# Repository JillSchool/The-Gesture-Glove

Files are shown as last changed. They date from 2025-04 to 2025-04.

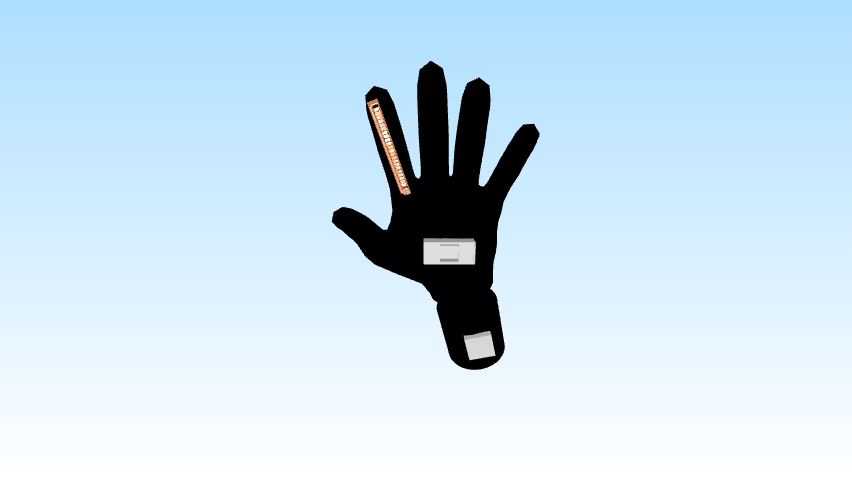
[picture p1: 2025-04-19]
Ontwerp/Gesture Glove/glove_design_v2.gif

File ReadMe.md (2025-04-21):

# The Gesture Glove – Tinlab1 Embedded Systems

In deze opleverset is het project *The Gesture Glove* van Tinlab1 Embedded Systems te vinden. De Demo videos en presentatie staan alleen in de opleverset.

## 📁 Onderdelen Opleverset

### 📂 Code

- **Auto**  
  Bevat de code voor de auto.

- **Gesture Glove**  
  Bevat de code voor de Gesture Glove.

- **Simulatie**  
  Bevat de simulatiewereld inclusief bijbehorende controllers.

- **TestCodes**  
  Bevat drie test codes gebruikt voor het project.

---

### 📂 Demo

- **Presentatie** 
  Bevat de eindpresentatie
  
- Bevat demo-video's:
  - Eén met de auto
  - Eén met de simulatie

---

### 📂 Documentatie

- **Handleiding**  
  Handleiding van de Gesture Glove.

- **Onderzoeken**  
  Sensoronderzoek.

- **Overig**  
  Informatie over de content van het displayscherm en de Gesture Glove.
  De projectdoelenchecklist.
  Een verslag met daarin alle belangrijke gegevens van het project.

- **Paper**  
  Engelstalige paper over het project.

- **Testen**  
  Testplan en testrapport.

- **Userstorys en requirements**  
  Bevat:
  - Moscow-document  
  - Requirements  
  - Userstory's met bijbehorende acceptance criteria

---

### 📂 Ontwerp

- **Elektrisch Schema**
  - **Auto**  
    Elektrisch schema van de auto.
  - **Gesture Glove**  
    Elektrisch schema van de Gesture Glove.

- **Gesture Glove**  
  Ontwerp van de Gesture Glove, het ontwerp voor het displayscherm en een architectuur diagram.

---

## Startpunt

Om de opleverset zo goed mogelijk te begrijpen is het van belang om te beginnen bij het document: Documentatie/Overig/The Gesture Glove. In dit document worden de context van het project, de hoofd- en deelvragen, de behaalde technische doelstellingen en een advies voor de verdere ontwikkeling van het project beschreven.

## Linkjes
- **Git:**
  https://github.com/JillSchool/The-Gesture-Glove.git
- **Trello:**
  https://trello.com/invite/b/67acb1cadb1ab3d7d48880f9/ATTIae5f5ea5cc120697c15d977ca467ee1fF77474C3/planning

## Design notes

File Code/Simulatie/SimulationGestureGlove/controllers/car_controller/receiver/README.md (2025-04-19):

# RX_BLE.py

## Overview

The `rx_ble.py` script facilitates communication between a BLE-enabled motion detection glove and a Webots simulation. It is designed to handle BLE device scanning, establish a TCP connection with Webots, and manage data transmission between the BLE device and the Webots simulation.

## Features

- Scans for available BLE devices.
- Connects to a Webots simulation via a TCP socket.
- Receives data from a BLE-enabled glove and forwards it to Webots.
- Sends test messages to Webots to verify the connection.
- Handles BLE disconnection events gracefully.

## Requirements

- Python 3 (tested with Python 3.12)
- Install the required Python packages listed in `requirements.txt`.

## Constants

- `GLOVE_ESP32_BLE_ADDRESS`: BLE address of the glove ESP32 device.
- `GLOVE_ESP32_BLE_CHARACTERISTIC_UUID`: UUID of the BLE characteristic to read data from.
- `WEBOTS_TCPIP_IP_ADDRESS`: IP address for the Webots TCP connection.
- `WEBOTS_TCPIP_PORT`: Port for the Webots TCP connection.

## Global Variables

- `webots_reader`: Reader object for Webots TCP connection.
- `tx_writer`: Writer object for Webots TCP connection.
- `cmd_prev`: Stores the previous command received from BLE.

## Functions

### `main()`

The main function manages BLE and Webots connections. It initializes BLE scanning, connects to Webots, and handles BLE data reception.

### `scan_ble_devices()`

Scans for available BLE devices and prints their details.

### `connect_to_webots()`

Establishes a TCP connection to the Webots simulation.

### `close_connection()`

Closes the TCP connection to Webots.

### `cleanup()`

Resets global variables and events for cleanup.

### `test_webots_connection(message="P")`

Sends a test message to Webots to verify the connection.

### `rx_from_ble()`

Receives data from the BLE device and forwards it to Webots.

### `tx_to_webots(message)`

Sends a message to Webots via the TCP connection.

### `loop_iteration(use_scan=False, use_connect=True, use_test=False, use_rx=True)`

Performs a single iteration of the main loop, handling BLE scanning, Webots connection, test message sending, and BLE data reception.

## Usage

1. Ensure Python 3.7 or higher is installed.
2. Install the required Python packages using `requirements.txt`:

   ```bash
   pip install -r requirements.txt
   ```

3. Run the script using Python:

   ```bash
   python rx_ble.py
   ```

4. The script will scan for BLE devices, connect to Webots, and handle data transmission.

## Notes

- Update the `GLOVE_ESP32_BLE_ADDRESS` constant with the correct BLE address of your glove device.
- Ensure Webots is running and accessible at the specified IP and port.

## License

This script is provided under the MIT License. See the LICENSE file for details.

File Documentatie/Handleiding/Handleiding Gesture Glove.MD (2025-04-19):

# Handleiding Gesture Glove

## Inhoudsopgave
- [Handleiding Gesture Glove](#handleiding-gesture-glove)
  - [Inhoudsopgave](#inhoudsopgave)
  - [1. Introductie](#1-introductie)
  - [2. Benodigdheden](#2-benodigdheden)
    - [2.1 Hardwarecomponenten van de Gesture Glove](#21-hardwarecomponenten-van-de-gesture-glove)
    - [2.2 Hardwarecomponenten van de auto](#22-hardwarecomponenten-van-de-auto)
    - [2.3 Software](#23-software)
  - [3. Werking van de Gesture Glove](#3-werking-van-de-gesture-glove)
    - [Bewegingen](#bewegingen)
    - [Extra functionaliteiten](#extra-functionaliteiten)
    - [OLED-scherm weergave](#oled-scherm-weergave)
      - [Linkerkant:](#linkerkant)
      - [Rechterkant:](#rechterkant)
    - [Verbinden met simulatie of fysieke auto](#verbinden-met-simulatie-of-fysieke-auto)
    - [ChangeLog](#changelog)

---

## 1. Introductie

De **Gesture Glove** is een project dat handbewegingen meet en doorstuurt naar een eindapparaat, zoals een RC-auto of een simulatieprogramma. Deze methode van data-overdracht biedt een alternatieve manier om apparaten aan te sturen en opent nieuwe toepassingen.

In dit project wordt de data gebruikt om een RC-auto te besturen in zowel de fysieke als de virtuele (simulatie) wereld. In deze handleiding wordt uitgelegd hoe het systeem werkt, welke onderdelen je nodig hebt en hoe je ermee aan de slag gaat.

---

## 2. Benodigdheden

Om dit project zelf op te bouwen, heb je de volgende hardware en software nodig:

### 2.1 Hardwarecomponenten van de Gesture Glove
- LilyGO TTGO T2 ESP32-WROOM (microcontroller met ingebouwd OLED-scherm)
- MPU6500 (versnellingsmeter en gyroscoopsensor)
- Flex sensor  
- Drukknop  
- Batterij

### 2.2 Hardwarecomponenten van de auto
- 4 DC-motoren  
- 4 wielen  
- ESP32S (microcontroller)  
- L293D motor driver  
- Batterij

### 2.3 Software
- Webots (simulatieomgeving)  
- Arduino IDE (voor het programmeren van de microcontrollers)

---

## 3. Werking van de Gesture Glove

De Gesture Glove maakt gebruik van verschillende sensoren om de beweging van je hand te registreren. Deze informatie wordt draadloos via **Bluetooth (BLE)** verzonden naar zowel de simulatie als de fysieke auto.

### Bewegingen
- **Voor- en achteruit:** De MPU6500 detecteert de kanteling van je hand. Kantel je hand naar voren, dan rijdt de auto vooruit. Kantel je hand naar achter, dan rijdt hij achteruit.
- **Links/rechts:** Bij kanteling naar links of rechts beweegt de auto in dezelfde richting.

### Extra functionaliteiten
- **Flex sensor:** Detecteert of je een vuist maakt. Als je een vuist maakt, remt de auto direct.
- **Drukknop:** Schakelt alle functies uit. Na 5 seconden gaat de glove in slaapmodus. Deze vertraging voorkomt dat een per ongeluk indrukken meteen tot slaapmodus leidt.

### OLED-scherm weergave
Op het scherm van de ESP32 worden realtime gegevens getoond:

#### Linkerkant:
- 🔋 **Batterij en hand:** Percentage van de batterij van de Gesture Glove  
- 📶 **Verbinding:** Signaalsterkte tussen de glove en de auto (fysiek of simulatie)  
- 🔋 **Batterij en stuur:** Batterijniveau van de fysieke auto  
- 🚗 **Snelheidsmeter:** Toont de snelheid van het voertuig  

#### Rechterkant:
- ❌ **'X'-icoon bovenaan:** Geeft aan of de werking is uitgeschakeld door de knop (hardware interrupt)  
- 🧭 **Richting onderaan:** Richting van de hand zoals gemeten door de IMU  
  - De gekleurde cirkel geeft de status van de rem aan:
    - **Groen & klein:** Geen vuist → geen rem  
    - **Rood & groter:** Vuist → rem actief  

---

### Verbinden met simulatie of fysieke auto

- **Simulatie:** Start de Webots-wereld en run het bijbehorende Python-script om verbinding te maken via BLE.
- **Fysieke auto:** Sluit de auto aan op stroom. De verbinding met de Gesture Glove wordt automatisch opgezet via BLE.

---

### ChangeLog

| Versie | Datum | Wijziging |
|---|---|---|
| 0.1 | 14-04-2025  | Document aangemaakt  |
| 1.0 | 15-04-2025  | Informatie toegevoegd |

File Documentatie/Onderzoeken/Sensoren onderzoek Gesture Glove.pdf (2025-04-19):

## Sensoren onderzoek Gesture Glove

## 1. Introductie

In dit onderzoek zijn de onderbouwde keuzes terug te vinden die gemaakt zijn om voor bepaalde hardware en software te kiezen.

## 2. Hardware

2.1 Microcontroller Gesture Glove
Om de data van de Gesture Glove te kunnen verwerken en sensorwaarden betrouwbaar te kunnen meter, is een geschikte microcontroller nodig. Deze moet krachtig genoeg zijn om meerdere sensoren tegelijkertijd aan te sturen, verbinding te maken met andere apparaten, en data in realtime te verwerken en eventueel weer te geven op een display. Ook is het van belang dat het een Low-power microcontroller is, zodat de batterij langer meegaat. Er is onderzoek gedaan naar een aantal microcontrollers.
- Arduino
De Arduino is een gebruikersvriendelijke en toegankelijke microcontroller. Deze is ideaal voor kleinschalige projecten, maar mist de ingebouwde communicatiemogelijkheid van Wifi of Bluetooth. Ook heeft de Arduino een gelimiteerde rekenkracht, wat voor dit project wel nodig is dankzij de meerdere sensoren en realtime dataverwerking. Ook moet je bij gebruik van de Arduino een extra OLED-display aansluiten.
- Raspberry Pi
De Raspberry Pi is een krachtige microcontroller. De Raspberry Pi bevat ingebouwde Wifi en Bluetooth. Het stroomverbruik is wel relatief hoog, en de Raspberry Pi zelf is te groot voor het project. De Raspberry Pi Pico is dan wel een stuk kleiner, maar bevat dan weer geen ingebouwde Wifi of Bluetooth. Ook zou je voor beide microcontrollers een extra OLED-display moeten aansluiten.
- ESP32s
De ESP32s, of de ESP Wroom 32, is een relatief kleine microcontroller met ingebouwde Wifi en Bluetooth. De microcontroller is geschikt voor het realtime verwerken van de data en het draadloos te communiceren met bijvoorbeeld een fysieke auto of simulatie wereld. Ook is de ESP32s energiezuinig. Alleen moet je voor deze ESP ook een externe OLED-Display hebben.
- ESP32 ESP-WROOM-32 met een 0.96" OLED-display
Deze versie van de ESP32 heeft alle voordelen van een ESP32 maar dan met een ingebouwde OLED-display scherm.
- LilyGO TTGO T2 ESP32-WROOM
De LiliGO is een variant van de ESP32 met een geïntegreerd OLED-Display scherm. Ook heeft deze ESP de mogelijkheid van Wifi en Bluetooth, is energiezuinig en is compact genoeg voor de Gesture Glove. Ook heeft deze microcontroller al een ingebouwde OLED-Display. De krachtige LiliGO TTGO T2 ESP32-WROOM is een ideale microcontroller.
Na een aantal Microcontrollers voor de Gesture Glove vergeleken te hebben, kunnen we concluderen dat de LiliGO TTGO T2 ESP32-WROOM de beste keuze is. Deze microcontroller voldoet aan alle eisen die nodig zijn binnen het project. Hij is energiezuinig, heeft de mogelijkheid om Wifi en Bluetooth te gebruiken en heeft een ingebouwde OLED-Display om de data realtime te kunnen laten zien.
2.2 Microcontroller Fysieke auto
Ook de fysieke auto heeft een microcontroller nodig. Deze microcontroller moet 4 wielen kunnen aansturen en via Wifi of Bluetooth data kunnen ontvangen van de Gesture Glove. Ook moet de microcontroller niet al te veel energie verbruiken.
- Arduino
De Arduino is een gebruikersvriendelijke en toegankelijke microcontroller. Deze is ideaal voor kleinschalige projecten, maar mist de ingebouwde communicatiemogelijkheid van Wifi of Bluetooth. Hierdoor is deze niet geschikt voor de auto.
- Raspberry Pi
De Raspberry Pi is een krachtige microcontroller. De Raspberry Pi bevat ingebouwde Wifi en Bluetooth. Het stroomverbruik is wel relatief hoog. De Raspberry Pi Pico verbruikt minder energie, maar bevat dan weer geen ingebouwde Wifi of Bluetooth. Deze zijn dus ook niet geschikt voor de auto.
- ESP32s

De ESP32s, of de ESP Wroom 32, is een relatief kleine microcontroller met ingebouwde Wifi en Bluetooth. De microcontroller is geschikt voor het realtime verwerken van de data en het draadloos te communiceren met de Gesture Glove. Hierdoor is deze ESP een goede keuze voor de auto.
Voor de auto is gekozen om gebruik te maken van de ESP32s. Deze microcontroller verbruikt minder energie en kan communiceren via Wifi en Bluetooth. Een prima microprocessor voor de auto.

2.3 Beweging detectie
Om de beweging van iemand hand te kunnen detecteren is er een sensor nodig. De sensor moet kunnen detecteren dat iemand zijn hand beweegt. De sensor moet dus een acceleratie meter en een gyroscoop bevatten. Een magnetometer is geen verijsde, maar we een voordeel als de sensor het bevat. Ook moet de sensor klein en licht zijn, zodat hij op de handschoen geplaatst kan worden.
- LSM6DS3
De LSM6DS3 sensor is een sensor die de gyroscoop van 3 assen kan meten en de acceleratie van 3 assen. De sensor is energiezuinig en werkt met I2C. De sensor bevat alleen geen magnetometer, dus er is geen absolute oriëntatie.
- LSM9DS1
De LSM9DS1 sensor meet de gyroscoop van 3 assen, de acceleratie van 3 assen en heeft de 3-assige magnetometer. Het is een krachtige sensor met veel opties. Helaas maakt dit de sensor moeilijk om mee te werken en duurder dan de andere alternatieven.
- BMI160
De BMI160 is een sensor met een zeer laag energiegebruik. De sensor heeft de gyroscoop en de acceleratie meter. Deze waardes worden gemeten met zeer hoge precisie. De sensor bevat geen magnetometer.
- BNO055
De BNO055 is een complexe sensor die een groot aantal data kan meten. Zo meet de sensor de acceleratie, gyroscoop, magnetometer en bevat hij een intern algoritme voor absolute oriëntatie. Het nadeel hiervan is dat de sensor een hoge energieconsumptie heeft en groter is dan de andere alternatieven. Ook is deze sensor een stuk duurder.
- MPU9250/6500
De MPU9250/6500 is een sensor met een 3-assige gyroscoop, 3-assige acceleratiemeter en een 3-assige magnetometer. De sensor is relatief klein en licht. De sensor is makkelijk om te gebruiken.
Voor het meten van de beweging van je hand is er gekozen voor de MPU9250/6500 sensor. De sensor kan alle assen meten en is makkelijk te gebruiken voor het project. Ook is hij licht en kosten efficiënt.

2.4 Buiging detectie
Een andere beweging van de hand die gedetecteerd moet kunnen worden is de buiging van je hand. De sensor moet dus kunnen meten of jij een vuist maak door de verbuiging van je vingers.
- Bend sensor
Deze sensor is dun en flexibel. Hij is relatief makkelijk te gebruiken, maar heeft een korte levensduur bij veel buigen.
- ToF (Time of Flight) sensor
Deze sensor meet de afstand tussen je vingertop en je handpalm. Het is een nauwkeurige sensor. Echter is deze sensor gevoelig voor licht en reflectie, en is hij moeilijk in de handschoen te verwerken.
- Flex sensor
Deze sensor is makkelijk te gebruiken, hij is licht en makkelijk te implementeren. De sensor is niet extreem nauwkeurig, maar het kan detecteren wanneer je een vuist maak.
Voor het project Gesture Glove is gekozen voor de Flex sensor. De sensor is makkelijk te gebruiken en kan de buiging van je vingers meten. De data is dan niet extreem nauwkeurig, maar dat maakt voor dit project niet heel veel uit.

## 3. Software

3.1 Simulatie wereld
Om de sensor waardes te kunnen visualiseren in een online omgeving, is er een simulatie wereld nodig. Om deze wereld te maken moet er eerst gekeken worden naar de mogelijke simulatieprogramma’s. Het simulatieprogramma moet makkelijk te gebruiken zijn, realtime data kunnen ontvangen en verwerken en moet verbinding kunnen maken via bluetooth of Wifi.
- Gazebo
Gazebo is een populaire roboticasimulator die goed integreert met ROS en meerdere sensoren en hardware kan aansturen. Hoewel het zeer nauwkeurig is voor het simuleren van fysica en robotbesturing, bleken de mogelijkheden te geavanceerd voor dit project, waarin eenvoudige visualisatie van beweging voldoende is.
- Webots
Webots is een andere simulatieomgeving voor robotica met een gebruiksvriendelijke interface, wat het eenvoudig maakt om realtime sensordata te simuleren en te visualiseren. Hoewel het niet dezelfde diepe integratie met ROS biedt als Gazebo, is de eenvoud en efficiëntie van Webots ideaal voor het visualiseren van basis-handbewegingen op basis van sensorgegevens.
- Unity
Unity, dat vooral bekend staat als game engine, biedt hoge grafische kwaliteit en flexibiliteit voor het creëren van aangepaste visualisaties. De geavanceerde functies zijn echter vooral nuttig bij complexe simulaties, waardoor Unity minder efficiënt is voor onze behoeften, die zich richten op eenvoudige visualisatie van handbewegingen.

Na een aantal simulatieprogramma’s vergeleken te hebben, kan geconcludeerd worden dat Webots een goed simulatieprogramma is voor dit project. Het is makkelijk te gebruiken, maar bied genoeg functionaliteiten om voor het project ingezet te kunnen worden.
3.2 Programmeertalen
Nadat er gekozen is voor de ESP microcontrollers is er gekozen om deze te programmeren in de Arduino IDE. Hierom is de programmeertaal C/C++ gekozen.
De controller van de simulatie is geschreven in C.
De Bluetooth communicatie is geschreven in python.
Voor extra test bestanden is gekozen voor python.

## 4. Conclusie

Nu we voor alle componenten verschillende alternatieven onderzocht hebben, kunnen we nu een conclusie trekken per onderdeel.

De microcontroller voor de Gesture Glove is de LiliGO TTGO T2 ESP32-WROOM geworden. Het is een krachtige ESP met de mogelijkheid voor Wifi en Bluetooth. Ook heeft deze ESP een ingebouwde OLED-Display scherm waarop data geprint kan worden.
De microcontroller voor de Fysieke auto is de ESP32S. Deze ESP heeft de mogelijkheid om te verbinden via Wifi en Bluetooth.
Om Beweging te kunnen detecteren is gekozen voor de MPU9250/6500. De sensor kan alle assen meten en relevante data teruggeven.
Voor de buiging detectie is gekozen voor de Flex sensor. Deze sensor kan duidelijk weergeven of je een vuist van je hand gemaakt hebt of niet.
Voor de Simulatiewereld is gekozen voor Webots. Het simulatieprogramma biedt genoeg mogelijkheden binnen dit project en is relatief makkelijk te gebruiken.
De programmeertalen die gebruikt gaan worden binnen het project zijn C, C++ en Python.

## 5. ChangeLog

ChangeLog
Versie | Datum | Wijziging
0.1 | 14-02-2025 | Document aangemaakt
0.2 | 09-03-2025 | Sensoren toegevoegd
1.0 | 14-04-2025 | Definitieve versie

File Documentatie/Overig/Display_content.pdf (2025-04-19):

# Display content

## All possible data:

- Battery life
- Orientation of IMU(as arrows)
- Status of flex sensor(together with arrows)
- Status of emergency button
- Current gesture
- Connectivity status
- Info on the car(speed, direction, battery life)

## Multiple screens

### A main screen:

Appears when all is ready to go. Will show useful information:

- Battery percentage of the glove ; percentage
- Signal strength between glove and end device ; great/good/bad/NC(not connected)
- Battery of the end device ; percentage
- Feedback from the end device like speed if possible ; km/h
- Status of the hardware/ emergency interrupt ; no/ yes?
- Orientation of the glove ; a moving circle in another bigger circle
- Resistance from the flex sensor ; a circle that gets bigger the more resistance

### An all black screen:

Appears while the device is in sleep mode.

## When will what action take place?

### Sleep mode:

When the hardware interrupt is used once and not disabled within 5 seconds.

### Watchdog timer:

Will make sure that the sensors are measuring, the data is being displayed and send within defined time frame.

### Hardware interrupts:

When a button is pushed, all data transfer will be stopped and the device will be put into sleep mode if not pressed again. When in sleep mode press the button to start the device.

### Software interrupts:

When the connection is lost send an interrupt to connect again before further action is taken.

### Using RTOS / embedded Linux:

The esp32 will use its multiple cores and RTOS task creations to execute functions.

### Reading a sensor:

The chosen sensors(IMU and flex) will be constantly read, displayed on the glove display and send to the end device.

### Control an actuator:

The send data from the sensors over Bluetooth or WIFI will be used to control step or other motors on the end device.

## ChangeLog

ChangeLog
Versie | Datum | Wijziging
0.1 | 09-04-2025 | Document aangemaakt
1.0 | 14-04-2025 | Definitieve versie

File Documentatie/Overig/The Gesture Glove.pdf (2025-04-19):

# The Gesture Glove

## Literatuuronderzoek en technische verantwoording

## 1. Context

The Gesture Glove is een innovatieve oplossing voor datavisualisatie en apparaat besturing. Met behulp van een slimme handschoen die handbewegingen meet, kunnen uiteenlopende eindapparaten, zoals RC-auto’s, drones of andere voertuigen, eenvoudig aangestuurd worden.
Deze technologie biedt waardevolle toepassingen in zowel de medische als de industriële sector. Denk hierbij aan ondersteuning bij revalidatierobot of het uitvoeren van precisiewerk in risicovolle of slecht bereikbare omgevingen.
The Gesture Glove verkent een nieuwe manier van menselijke interactie met technologie, door realtime handbewegingen niet alleen te detecteren, maar ook weer te geven in een simulatie en te gebruiken om een auto aan te sturen.
Voor de realisatie van dit project is uitgebreid onderzoek gedaan naar verschillende aspecten van de technologie. Hierbij is onder andere gekeken naar geschikte sensoren voor het meten van bewegingen, methodes voor het verwerken van de data, geschikte communicatieprotocollen zoals BLE, energiebeheer voor draagbare toepassingen en de aansturing van het systeem zelf.
Om het project doelgericht en gestructureerd uit te voeren, is een hoofdvraag opgesteld. Deze hoofdvraag wordt beantwoord aan de hand van meerdere deelvragen.

## 2. Hoofdvraag

Om goed van start te gaan met het project, is er eerst overlegd met de projectdocent om de haalbaarheid te bespreken. Hieruit zijn een aantal Userstory’s en Requirements opgesteld. Hieruit is er een Hoofdvraag geformuleerd: “Hoe kun je met behulp van een slimme handschoen handbewegingen detecteren en visualiseren?”

## 3. Deelvragen

Om de hoofdvraag te kunnen beantwoorden zijn er een aantal deelvragen geformuleerd.

### 1. Welke bewegingen moeten gemeten kunnen worden?

Voor de besturing van een voertuig is het essentieel om de kanteling van de hand op de X en Y as accuraat te kunnen meten. Op basis van de richting en snelheid van deze kanteling kan het voertuig worden aangestuurd qua richting én snelheid. Daarnaast is het herkennen van het maken van een vuist een belangrijke actie, bijvoorbeeld als signaal om te remmen of een systeem te pauzeren. Dit zijn de twee primaire bewegingen die binnen het project zijn geïdentificeerd.

### 2. Hoe kunnen deze specifieke bewegingen gemeten worden?

Deze bewegingen worden gemeten met behulp van een IMU-sensor (MPU6500) die rotatie-en versnellingsgegevens levert, en met Flex sensor die buiging van de vingers detecteren, zoals bij het maken van een vuist. De plaatsing van de sensoren is belangrijk om de precies de juiste metingen te kunnen verrichten.
Voor het kiezen van de sensoren is een apart sensoren onderzoek uitgevoerd. Dit onderzoek is terug te vinden in de opleverset. Uit het sensorenonderzoek blijkt dat de MPU9520/6500 vanwege zijn stabiliteit, I2C-compatibiliteit en nauwkeurige gyroscoop- en versnellingsdata de beste keuze was. Voor de Flex sensor is gekozen vanwege de eenvoud en effectiviteit bij het meten van vingerbewegingen.

### 3. Hoe kunnen de gemeten waarden gevisualiseerd worden?

De visualisatie gebeurt op twee manieren:
- Softwarematig: Via een simulatieomgeving Webots, waarin een racebaan of virtuele omgeving is gesimuleerd. De handschoen bestuurt daarin een virtueel voertuig. Uit het sensorenonderzoek kwam naar voren dat Webots de beste mogelijkheid biedt tussen compatibiliteit en eenvoudige integratie.
- Hardware matig: De ESP LilyGO TTGO T2 is verbonden met een OLED-display waarop realtime informatie wordt weergegeven, zoals handoriëntatie, verbindingssnelheid en batterijstatus. Daarnaast wordt een fysieke auto bestuurd met de data van de handschoen.

### 4. Hoe kan data het meest effectief worden verzonden van de ESP naar een laptop?

Voor een snelle en energiezuinige communicatie is gekozen voor Bluetooth Low Energy (BLE). Deze technologie maakt het mogelijk om continu data te verzenden zonder grote batterijbelasting. In de Engelse Paper is meer informatie te vinden over waarom deze keus gemaakt is.

## 4. Technische verantwoording

Binnen het TinLab Embedded Systems zijn er een aantal verijsde technische doelen. Hieronder een overzicht van deze technieken en hoe ze toegepast zijn binnen het project. Watchdog timer
- Voorkomt dat het system vastloopt. Als de sensor input niet op tijd ontvangen wordt, wordt het systeem automatisch gereset.

Sleep modus
- Wanneer de hardware interrupt gebruikt wordt en niet binnen 5 seconde nog een keer ingedrukt wordt, gaat de Gesture Glove in de Sleep modus.

Hardware interrupt
- Wanneer de knop van de hardware interrupt ingedrukt wordt, wordt er geen data meer verzonden. Hierdoor kan je je hand vrij bewegen zonder data te verzenden. Wanneer de hardware interrupt knop niet nog een keer ingedrukt wordt binnen 5 seconde, gaat de Gesture Glove in sleep modus. Wanneer de hardware interrupt nog een keer ingedrukt wordt, start de Gesture Glove weer opnieuw op.

Software interrupt
- Herlaad de icoontjes op het display om de actuele data te tonen door een software interrupt die elke 2 seconden afgaat.

Gebruik van RTOS/ Embedded Linux
- Dankzij het gebruik van RTOS op de ESP32 kunnen meerdere processen tegelijk draaien, zoals sensoruitlezing en communicatie.

Communicatie via I2C en/of SPI
- De IMU-sensor communiceert via het I2C-protocol.

Uitlezen van een sensor
- Zowel de IMU als Flex sensor worden continu uitgelezen.

Regelen van een systeem (bij voorkeur met PID-controller)
- De MPU-sensor verwerkt de rauwe gyroscoop data van de sensor doormiddel van een PID-regelaar. Hierdoor neemt de snelheid van het eindapparaat geleidelijk toe.

Aansturen van een actuator
- De motor van de fysieke auto wordt aangestuurd via een L293D-motor driver. Hiermee wordt de auto aangestuurd.

Interfacing met een display

- De ESP LilyGO TTGO T2 ESP32-WROOM heeft een ingebouwde OLED-display. Hierop is de richting te zien waarop de Gesture Glove beweegt. Ook is hier de batterij waarde te zien, de verbinding snelheid en of de hardware interrupt actief is.

## 5. Advies

Wanneer er gekozen wordt om verder te bouwen op het project van de Gesture Glove is er een aantal adviezen om naar te kijken. Ten eerste wordt er geadviseerd om meer onderzoek te doen naar de plaatsing van de hardwarecomponenten op de Gesture Glove zelf. Dit kan lijden tot snellere en nauwkeurigere metingen van de bewegingen. Hierbij kan ook gekeken worden wat de mogelijkheden zijn van het meer implementeren van de sensoren, bijvoorbeeld door de Flex sensor in de handschoen te plaatsen.
Als tweede advies wordt meegegeven om krachtigere motoren te plaatsen onder de fysieke auto. Dit zorgt ervoor dat de auto sneller kan rijden en er een duidelijk verschil in snelheid van de auto gezien kan worden.
Als derde wordt geadviseerd om onderzoek te doen naar nieuwe sensoren die gebruikt kunnen worden voor nog meer bewegingen te kunnen detecteren. Dit bied nog meer mogelijkheden voor het aansturen van fysieke objecten.

## 6. Conclusie

De hoofdvraag " Hoe kun je met behulp van een slimme handschoen handbewegingen detecteren en visualiseren?" is beantwoord door het combineren van verschillende sensoren en het draadloze communiceren tussen de Gesture Glove, simulatie en fysieke auto.
Uit de deelvragen blijkt dat de twee belangrijkste bewegingen die gemeten moeten worden, het kantelen van de hand en het maken van een vuist zijn.
Deze bewegingen zijn betrouwbaar meetbaar dankzij de MPU9520/6500-IMU en Flex sensor, gekozen op basis van het sensorenonderzoek.
De metingen worden gevisualiseerd in een simulatieomgeving (Webots) en via een OLED-display op de ESP32, en worden vertaald naar actie in een fysiek voertuig.
De dataverzending vindt plaats via BLE, wat op basis van de vergeleken opties in de paper de meest effectieve methode bleek.
Het project bevat alle elementen van een compleet Embedded systeem: van realtime dataverwerking en sensoraansturing tot motorsturing en draadloze communicatie. Het project toont de potentie van draagbare besturingstoepassingen in verschillende omgevingen. Wel wordt geadviseerd om te kijken naar een robuustere versie van de handschoen voor langdurig gebruik in realistische omgevingen

## 7. ChangeLog

ChangeLog
Versie | Datum | Wijziging
0.1 | 07-04-2025 | Document aangemaakt
0.2 | 17-04-2025 | Hoofd + deelvragen
1.0 | 19-04-2025 | Advies + conclusie

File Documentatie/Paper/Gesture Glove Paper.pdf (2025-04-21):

# Gesture Glove System: Sensor Accuracy, Display Efficiency, and Visualization

Prashant Chotkan, Jamai Esseboom, Jill den Ouden

Abstract—This research explores the optimization of gesture-based interfaces by evaluating the performance of key components in a gesture glove system, including the MPU6500 motion sensor, flex sensors, and the SSD1331 OLED display. The study focuses on improving gesture recognition accuracy and real-time visualization, addressing common challenges such as sensor inaccuracies and display latency. Experimental tests reveal that partial updates on the SSD1331 OLED display enhance refresh rates, while the MPU6500 sensor provides precise tracking of hand movements. Flex sensors positioned on the back of the finger demonstrate superior accuracy in detecting finger curvature. These findings offer valuable insights for the development of more responsive and accurate gesture-based control systems. Index Terms—gesture recognition, MPU6500, flex sensors, SSD1331 OLED, real-time visualization, gesture glove, human-computer interaction

I. INTRODUCTION

Gesture-based interfaces are increasingly used in various applications, from assistive technologies to virtual reality, yet optimizing their performance remains a challenge. Existing gesture recognition systems often suffer from limitations such as inaccurate sensor data, slow response times, and poor visualization of gestures, which hinder usability and effectiveness. This research aims to evaluate the key components of a gesture glove system, specifically motion sensors (MPU6500), flex sensors, and the SSD1331 OLED display, to determine their impact on gesture recognition accuracy and real-time visualization. Understanding the limitations and capabilities of these components will help improve gesture-based control systems, making them more reliable and responsive.
This research is valuable to engineers, developers, and researchers working in human-computer interaction, wearable technology, and assistive devices. By providing data-driven insights into component performance, this study contributes to the design of more efficient and accurate gesture-based interfaces, which can benefit applications in healthcare, gaming, robotics, and augmented reality.

II. ASSIGNMENT DESCRIPTION

A. Problem Definition

Gesture-based interfaces are widely used in applications such as assistive technology, virtual reality, and human-computer interaction. However, existing gesture recognition systems face several challenges that hinder their usability and effectiveness. These challenges include inaccurate sensor data, slow response times, and poor real-time visualization of gestures, all of which reduce the reliability of such systems.

One of the main limitations is the accuracy of motion tracking and finger curvature detection. Many systems rely on inertial measurement units (IMUs) and flex sensors, but their placement, calibration, and data processing methods significantly impact recognition accuracy. Some systems rely on a camera and ai technology to detect gestures and hand movements which are very prone to instability issues. Additionally, real-time visualization of gestures remains inefficient, as current display technologies may introduce latency or fail to represent movements smoothly.
This research addresses these challenges by evaluating the MPU6500 motion sensor, flex sensors, and the SSD1331 OLED display in a gesture glove system. The study investigates how sensor placement, data processing strategies, and display update techniques influence gesture recognition accuracy and real-time visualization performance. By identifying the limitations of these components, this research aims to improve gesture-based control systems, making them more responsive, precise, and suitable for applications in healthcare, gaming, robotics, and augmented reality.
B. Requirements
- Finger Curvature Detection – The system must accurately detect and measure the bending of the fingers.
- Glove Position and Direction Tracking – The system must determine the orientation and movement of the glove.
- Real-Time Data Processing – The system must process and interpret sensor data with minimal latency for immediate feedback.
- Wireless Data Transmission over Wi-Fi – The system must transmit gesture data wirelessly to an external device for further processing or visualization.
- Simulated Hand Representation – The system must include a virtual hand model that visually replicates the detected gestures in real time for verification and analysis.

III. RESEARCH QUESTIONS

This research focuses on the question: How can a gesture glove system effectively detect finger curvature, track hand position, and provide real-time visualization? To break this down further, the following subquestions are explored.
1) How do different update strategies and timing intervals affect the responsiveness of the SSD1331 display?
2) How effectively does an MPU6500 track the position and movement of the glove?

3) How does flex sensor placement influence accuracy in measuring finger curvature?
4) How to digitally simulate a hand using real-time collected sensor data?

IV. METHODS

A. SSD1331 Display

The SSD1331 is a 96×64 pixel OLED display commonly used in embedded systems. Its refresh rate directly impacts smoothness and responsiveness, making it crucial for real-time applications. This study examines how update strategies (full-screen vs. partial updates) and refresh timing intervals affect display performance.
1) Research Question: How does the refresh rate of the SSD1331 display respond to different update strategies and timing intervals?
We hypothesize that
- Updating fewer pixels results in a faster refresh rate.
- A minimum processing time is required per refresh cycle.
- Excessively frequent refreshes may cause rendering artifacts or frame skipping.
The study is conducted using a TTGO T2 ESP32 board with an SSD1331 OLED display, programmed in C with the Arduino framework. The evaluation consists of two test cases:
- Full-Screen vs. Partial Updates: Measuring refresh time for a full-screen update compared to a smaller region (e.g., 10×10 pixels).
- Effect of Refresh Interval: Varying update intervals from a few milliseconds to hundreds of milliseconds to assess performance, potential artifacts, and frame skipping.
Results will determine optimal update strategies for improving display performance in real-time applications.
B. MPU6500
1) Relevance of the MPU Sensor: The MPU6500 is essential for tracking hand movement and orientation. It detects shifts along the X, Y, and Z axes (acceleration) and tilting (gyroscope), ensuring reliable hand gesture recognition.
2) Choosing the Right MPU: The MPU9250 was initially selected for its 9 degrees of freedom (gyro, accelerometer, and magnetometer) [2], allowing precise movement and absolute orientation tracking. Its compact size, strong documentation, and wide library support make it ideal. While alternatives like the ICM-20948 exist, the MPU9250 balances performance and availability. For applications not requiring absolute orientation, the MPU6050 is a simpler alternative. However, for stable tracking with minimal drift, a magnetometer-equipped sensor is preferred.
3) MPU Sensor Testing: Testing revealed that the provided sensor was the MPU6500 instead of the expected MPU9250. Despite this, efforts focus on successfully integrating the MPU6500 into the system.
a) Including the Libraries: To interface with the MPU6500 sensor, it is advisable to use a library that facilitates communication over I²C or SPI, as outlined in the sensor’s specifications [1]. Several open-source libraries are available that support the MPU6500, simplifying data retrieval from the sensor. The test setup will require the MPU6500 sensor and a compatible micro controller for proper integration.
b) Test Cases: For the test cases you will need a MPU6500 sensor, a ESP32 and a pc/laptop running arduino.ide and python. To run the code for MPU6500 you first need to connect the sensor to the ESP32.
- GND – Connect to GND
- VCC – Connect to 3.3V
- SCL – Connect to GPIO 22
- SDA – Connect to GPIO 21
4) IMU Acceleration: This test ensures that the Acceleration meter within the MPU6500 works as expected. Requirement: The system must detect various movements along the X, Y, and Z axes. These movements correspond to shifts in hand position.
- Description: When the hand is moved, the sensor transmits data to the serial monitor, displaying the X, Y, and Z values.
- Steps:
1) Connect the sensor.
2) Move the hand.
3) Verify whether the movements are detected.
- Acceptance Criteria: The movements must be correctly detected and printed in the serial monitor.
5) IMU Gyroscope: This test ensures that the Gyroscope meter within the MPU6500 works as expected. Requirement: The system must detect various hand movements, specifically tilting.
- Description: When the hand is moved, data is transmitted to the serial monitor. The data can be checked by rotating the sensor and hold it to a 90 degrees angle.
- Steps:
1) Connect the sensor.
2) Move the hand.
3) Verify whether the movements are detected.
- Acceptance Criteria: The movements must be correctly detected and printed in the serial monitor.
6) IMU Gyroscope Accuracy: This test ensures that the gyroscope within the MPU6500 provides reliable readings. Requirement: When the sensor is held at different angles, it should return accurate values.
- Description: The sensor’s output is tested at various angles to verify accuracy.
- Steps:
1) Connect the sensor.
2) Hold the sensor at a 90-degree angle.
3) Verify whether the measured angle matches the actual orientation.
- Acceptance Criteria: The measured value must not deviate by more than 5 degrees from the actual angle.

7) IMU Acceleration Accuracy: This test ensures that the accelerometer within the MPU6500 provides reliable readings. A Python program is used to visualize sensor data by displaying a moving cube that mimics the sensor’s motion. Requirement: When moving the sensor, it should return accurate acceleration values corresponding to the movement.
- Description: The sensor’s accuracy is tested by comparing its output to the motion of a virtual cube on a screen.
- Steps:
1) Connect the sensor.
2) Close the serial monitor, then start the Python program.
3) Move the sensor at different speeds and directions.
4) Verify whether the cube’s movement matches the sensor’s motion.
- Acceptance Criteria: The cube on screen must move in the same direction as the sensor and stop when the sensor stops moving.
C. Flex Sensor

A flex sensor was chosen to measure the bending angle or curvature of the fingers due to its simplicity and effectiveness in detecting finger movements. Compared to other alternatives such as inertial measurement units (IMUs) or strain gauges, flex sensors offer a straightforward integration process, consume low power, and provide analog output that can be easily processed by a microcontroller. While IMUs are not suitable for measuring the curvature of the fingers specifically, they can be used for detecting other movements. Strain gauges can be used to measure finger curvature, but they require precise placement on the glove and are less accurate than a flex sensor while also being relatively more expensive.
To evaluate the performance of the flex sensor in detecting hand gestures, a controlled test setup was designed. The sensor was attached to the index finger at two different locations, as shown in Fig. 1:
1) Inside the finger (palm-side placement) – to measure curvature directly as the finger bends inward.
2) Outside the finger (backhand placement) – to analyze if it provides a more stable or accurate reading.
The sensor was connected to an ESP32 microcontroller’s Analog-to-Digital Converter (ADC) pin to continuously measure the resistance change as the finger moves. A custom testing procedure was followed:
- The hand started in a fully open and straight position.
- The subject gradually curled their fingers into a tight fist over a period of 5 seconds.
- ADC values were recorded in real-time and logged for analysis.
- The test was repeated multiple times to ensure consistency and identify the optimal placement of the sensor.

Fig. 1. Flex Sensor Placement

This experiment aimed to determine the most effective sensor placement by analyzing the signal consistency. By systematically comparing the ADC readings, the goal was to identify the placement that provides the clearest and most reliable data for detecting hand gestures accurately.

D. Simulation

To visualize the sensor data in real-time, we evaluated three simulation programs: Gazebo, Webots, and Unity. The primary goal was to simulate hand movements based on real-time sensor input without requiring complex features such as collision detection. The simulation program simply needed to receive and visualize the sensor data, translating it into hand movements.
1) Simulation Program Evaluation: The programs will each be tested separately by setting them up and trying a simple simulation. We compared the three simulation tools based on their ease of use and ability to visualize hand movements effectively.
- Gazebo: Gazebo is a popular robotics simulator that integrates well with ROS and can handle multiple sensors and hardware. While it is highly accurate for simulating physics and controlling robots, its capabilities were found to be more advanced than necessary for this project, where simple movement visualization suffices.
- Webots: Webots is another robotics simulation tool with a user-friendly interface, making it easy to simulate and visualize real-time sensor data. While it lacks the deep integration with ROS found in Gazebo, its simplicity and efficiency make it ideal for visualizing basic hand movements based on sensor inputs.
- Unity: Unity, typically used for game development, offers high-quality graphics and flexibility for creating custom visualizations. However, its advanced features are better suited for complex simulations, making it less efficient for our needs, which focused on straightforward hand movement visualization.
V. RESULTS
A. SSD1331 Display

The collected data shows the following trends:

- Full-screen updates take significantly longer than partial updates. The function fillScreen() required approximately 172 ms to complete, whereas updating a small 10x10 pixel region only took around 3 ms.
- Partial updates are significantly more efficient than full-screen redraws. This suggests that applications should avoid unnecessary full refreshes and instead update only necessary regions to optimize performance.
- No missing frames were observed even at high refresh rates. To verify this, slow-motion recording was used, which confirmed that frames were rendered sequentially without drops or skips.

B. MPU6500
All tests for the MPU6500 sensor were successfully executed, verifying its expected functionality. The results for each test are summarized below:
1) IMU Acceleration Test: The sensor correctly detected motion along the X, Y, and Z axes. Data was displayed in the serial monitor, confirming expected functionality.
2) IMU Gyroscope Test: The gyroscope accurately detected tilting movements. At a 90-degree angle, the measured values corresponded to the expected rotation, meeting the acceptance criteria.
3) IMU Gyroscope Accuracy Test: Measured values deviated by no more than 3 degrees from expected orientations, within the ±5-degree tolerance, confirming accuracy.
4) IMU Acceleration Accuracy Test: A Python program displayed a virtual cube mimicking sensor movement. The cube moved accurately in sync with the sensor, verifying data reliability.
All acceptance criteria were met, demonstrating the MPU6500’s capability to measure acceleration and angular velocity reliably in motion detection applications.
C. Flex Sensor
The results of the flex sensor tests demonstrated that both placements provided similar trends in ADC readings, ranging from 0 (completely unbent) to a maximum of 3038 (tight fist). However, the backhand placement showed slightly lower maximum adc value indicating a lower measuring range.
Time (s) | 0 | 1 | 2 | 3 | 4 | 5
Palm-Side Placement | 0 | 751 | 1507 | 2251 | 2898 | 3038
Backhand Placement | 0 | 724 | 1478 | 2207 | 2854 | 3030
TABLE I
ADC READINGS OVER TIME FOR FLEX SENSOR AT DIFFERENT PLACEMENTS.

As seen in Table I, the palm-side placement provided slightly more curvature compared to the backhand placement, which showed minor variations in maximum ADC values. Furthermore bending of the flex sensor when placed palm-side appeared more difficult as bending the fingers decreases the surface on which the flex sensor is mounted. This leads to the flex sensor getting loose from the finger. On the backhand placement the flex sensor is more stable as the contact surface increases a little when bending the fingers. This indicates that the sensor is more stable when positioned on the backhand.

D. Simulation
After comparing and testing the three options, Webots was selected as the most suitable tool for this project due to its balance of simplicity, and ease of use in real-time data visualization. Furthermore this program was easiest to setup overall, making it more accessible for rapid prototyping and iteration. Its user-friendly interface, combined with robust documentation and community support, facilitated quick development cycles, which were crucial for meeting project deadlines

VI. CONCLUSION
This study successfully integrated key components for a gesture-controlled embedded system, with a focus on performance optimization and accurate hand gesture recognition. The MPU6500 sensor proved reliable for motion and orientation tracking, ensuring precise hand movement detection through both accelerometer and gyroscope data. The flex sensor, placed on the backhand, provided consistent and accurate curvature detection, essential for recognizing gestures like bending. The SSD1331 display showed improved performance when using partial updates, avoiding frame loss and ensuring smoother real-time interactions. Webots was chosen as the simulation tool for its ease of use and effective visualization of real-time sensor data. This work demonstrates the importance of sensor placement and optimization in achieving reliable gesture recognition and provides a foundation for enhancing real-time embedded applications. Further testing could explore the impact of different display controllers, SPI clock speeds, and alternative sensor placements to further improve system performance.

VII. REFERENCES

1) TDK InvenSense, MPU-6500 Product Specification,
Revision | 1.3, | Document | Number: | PS-MPU-
6500A-01, | June | 2020. | [Online]. | Available:
https://invensense.tdk.com/wp-content/uploads/2020/06/PS-MPU-6500A-01-v1.3.pdf
2) InvenSense Inc., “MPU-9250 Product Specification,” PS-MPU-9250A-01, Jun. 2016. [Online]. Available: https://invensense.tdk.com/wp-content/uploads/2015/02/PS-MPU-9250A-01-v1.1.pdf
3) LilyGO, “GitHub - LilyGO/TTGO-T2-SSD1331-SD: TTGO-T2 V1.6,” GitHub. Available: https://github.com/LilyGO/TTGO-T2-SSD1331-SD

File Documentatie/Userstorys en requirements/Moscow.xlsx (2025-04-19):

Moscow
Must
1 | De handschoen bevat een sensor die het bewegen van je hand kan meten. Deze waardes worden doorgestuurd naar een simulatie programma.
2 | De handschoen bevat een sensor die de rotatie van je hand kan meten. Deze waardes worden doorgestuurd naar een simulatie programma.
3 | De handschoen bevat een sensor die het maken van een vuist kan meten. Deze waardes worden doorgstuurd naar een simulatie programma.
4 | Belangrijke waardes van de handschoen worden geviaualiseerd op de display van de ESP.
5 | Een simulatie programma kan alle gemete waardes weergeven.
6 | Het project moet gebruik maken van een watchdog timer
7 | Het project moet gebruik maken van een sleep modus
8 | Het project moet gebruik maken van een hardware interrupt (button) | Het indrukken van de knop zorgt ervoor dat de sensor waardes niet langer doorgestuurd worden, waardoor je je hand vrij kan bewegen. De display gaat in sleep modus.
9 | Het project moet gebruik maken van een software interrupt (Flex sensor)
10 | Het project moet gebruik maken van RTOS
11 | Het project moet gebruik maken van SPI en I2C (ESP en IMU)
12 | Het project moet gebruik maken van een PID (IMU)
13 | Het project moet een actuator aansturen
14 | Het project is verbonden door middel van WiFi/bluetooth
Should
15 | De sensor waardes stuurt een motor aan. Nog geen complete auto.
Could
16 | De sensor waardes sturen een autotje aan.
17 | De handschoen trilt als feedback.
18 | Een button zet de glove compleet uit.
Won't

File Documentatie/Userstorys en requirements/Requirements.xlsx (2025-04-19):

Requirement ID | Requirement | Task
1 | Er moet onderzoek gedaan worden naar welke sensoren het beste gebruikt kunnen worden. | Onderzoek naar de mogelijkheden van sensoren
2 | De IMU sensor moet beweging meten op de X, Y en Z as | Het systeem moet in staat zijn om de positie van de hand in de X, Y en Z dimensies te meten door middel van de IMU sensor. De X, Y en Z waardes moeten real-time gemeten worden en weergegeven in de Terminal of Serial monitor.
3 | De IMU sensor moet rotatie meten | Het systeem moet in staat zijn om de rotatie van de hand te meten door middel van de IMU sensor. De rotatie waardes moeten real-time gemeten worden en weergegeven in de Terminal of Serial monitor.
4 | De Flexsensor moet de buiging van de vinger meten/ het maken van een vuist | Het systeem moet in staat zijn om de buiging van de hand te meten door middel van de Flex sensor. De buiging waardes moeten real-time gemeten worden en weergegeven in de Terminal of Serial monitor.
5 | De ESP Display moet de batterijstatus weergeven | Het systeem moet de batterijstatus van de Gesture-Control Glove meten en bijhouden. De batterij status moet worden weergegeven op de ESP Display.
6 | De IMU waardes van de X, Y en Z as moeten op de ESP Display weergeven worden | De ESP Display moet real-time de waardes van de bewegingsrichting tonen
7 | De IMU waareds van de rotatiemoet op de ESP Display weergeven worden | De ESP Display moet real-time de waardes van de rotatie tonen
8 | De Flexsensor waarde moet op de ESP Display weergeven worden | De ESP Display moet real-time de waardes van de Flexsensor tonen
9 | Er moet een knop zijn die de sensor input stopt | Het systeem moet een fysieke knop bevatten waarmee de gebruiker de sensorinput tijdelijk kan uitschakelen. Wanneer de knop ingedrukt wordt, moet het systeem direct stoppen met het versturen van de sensor waardes
10 | Alle gemete sensor waardes moeten gestuurd worden naar een simulatie programma | Er moet onderzocht worden welk simulatie programma het meest geschikt is voor het project. Het programma moet alle sensor waardes ontvangen en netjes visualiseren.
11 | Er moet onderzoek gedaan worden naar of Wifi of Bluetooth een betere oplossing is voor het versturen van data. | Onderzoek naar de mogelijkheden van wifi en bluetooth voor dit project.

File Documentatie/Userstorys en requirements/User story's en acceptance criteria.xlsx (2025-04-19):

User Story ID | User story | Task | Acceptance Criteria
1 | Als een gebruiker wil ik dat de beweging van mijn hand op de X, Y en Z as gemeten kan worden. | De IMU sensor moet waardes kunnen meten van de X, Y en Z as De gemete waardes kunnen uitgelezen worden in de Terminal/serial monitor | De IMU sensor moet de waardes nauwkeurig meten.
2 | Als een gebruiker wil ik dat de rotatie van mijn hand gemeten kan worden. | De IMU sensor moet waardes kunnen meten van de rotatie De gemete waardes kunnen uitgelezen worden in de Terminal/serial monitor | De IMU sensor moet de waardes nauwkeurig meten.
3 | Als een gebruiker wil ik dat het openen en sluiten van mijn hand gemeten kan worden. | De flex sensor moet de waardes kunnen meten van de buiging van de sensor. De gemete waardes kunnen uitgelezen worden in de Terminal/serial monitor | De Flex sensor moet de buiging juist kunnen meten.
4 | Als een gebruiker wil ik de batterij waardes van mijn Gesture-Control Glove kunnen lezen. |  | De Display van de ESP geeft de batterij status weer
5 | Als gebruiker wil ik op de display kunnen zien welke kant ik mijn hand op beweeg. | Op de Display van de ESP wordt weergeven welke kant je je hand op beweeg. | De Display van de ESP toont de beweging
6 | Als gebruiker wil ik op de display kunnen zien of ik een vuist maak. | Op de Display van de ESP wordt weergeven dat je een vuist van je hand maak | De Display van de ESP toont het maken van een vuist.
7 | Als gebruiker wil ik binnen een simulatie programma kunnen zien wat alle sensor waardes zijn | Van de IMU moeten de X, Y en Z waardes doorgestuurd worden naar de simulatie Van de IMU moet de rotatie in grades doorgestuurd worden naar de simulatie Van de Flex sensor moeten de waardes doorgestuurd worden naar de simulatie Van de button moet de status doorgestuurd worden naar de simulatie | Het simulatie programma krijgt alle waardes binnen en toont deze op een overzichtelijke mannier
8 | Als gebruiker wil ik een knop die ervoor zorgt dat ik mijn hand vrij kan bewegen zonder daar sensor waardes van te sturen | Er moet een knop zijn die, wanneer ingrdrukt, ervoor zorgt dat er geen sensor input verstuurd wordt. | Het indrukken van de knop stopt direct het versturen van sensor input.

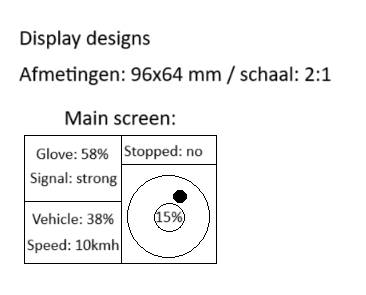
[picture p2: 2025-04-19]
Ontwerp/Gesture Glove/DisplayDesign.png

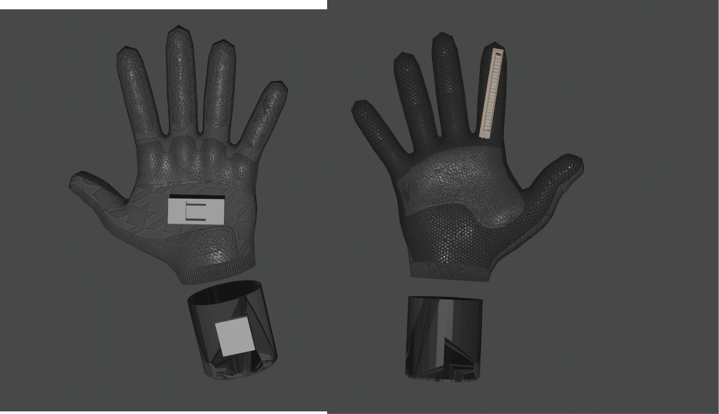
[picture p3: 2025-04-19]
Ontwerp/Gesture Glove/glove_design.png

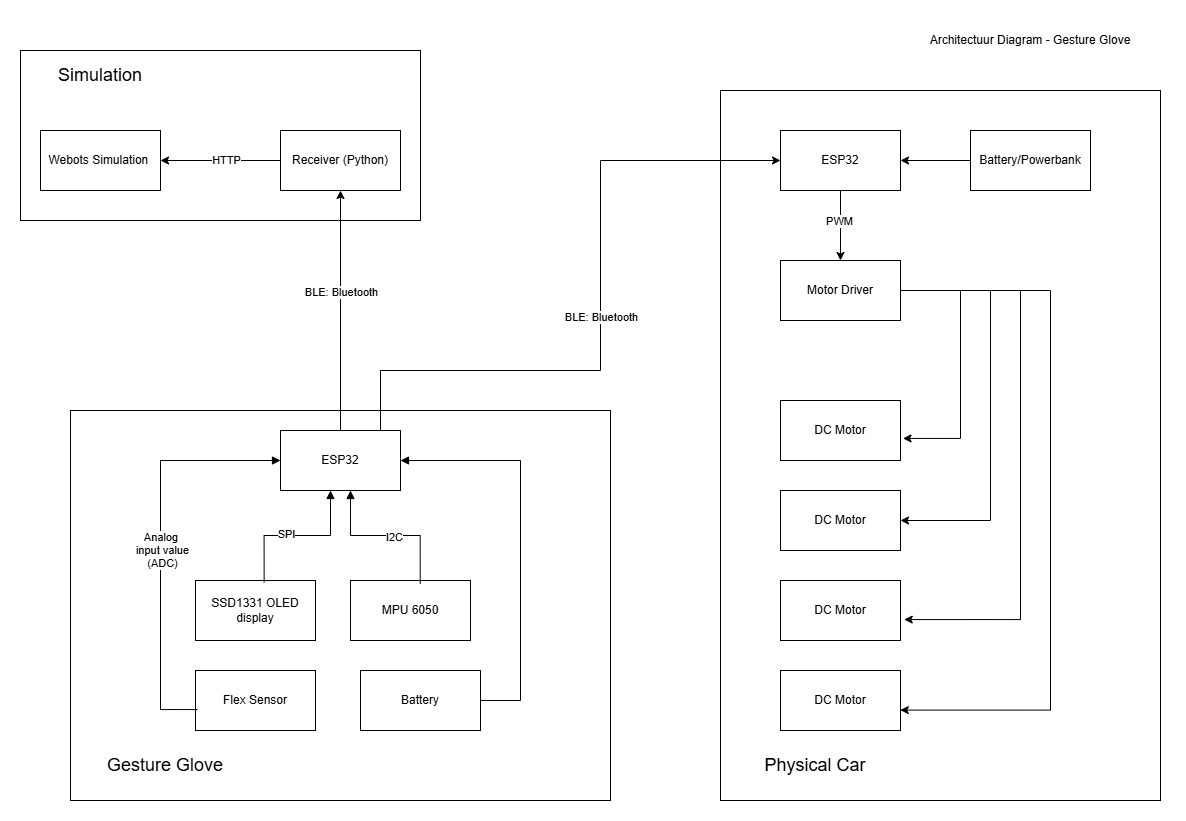
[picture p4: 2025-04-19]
Ontwerp/Gesture Glove/architectuur_diagram.png

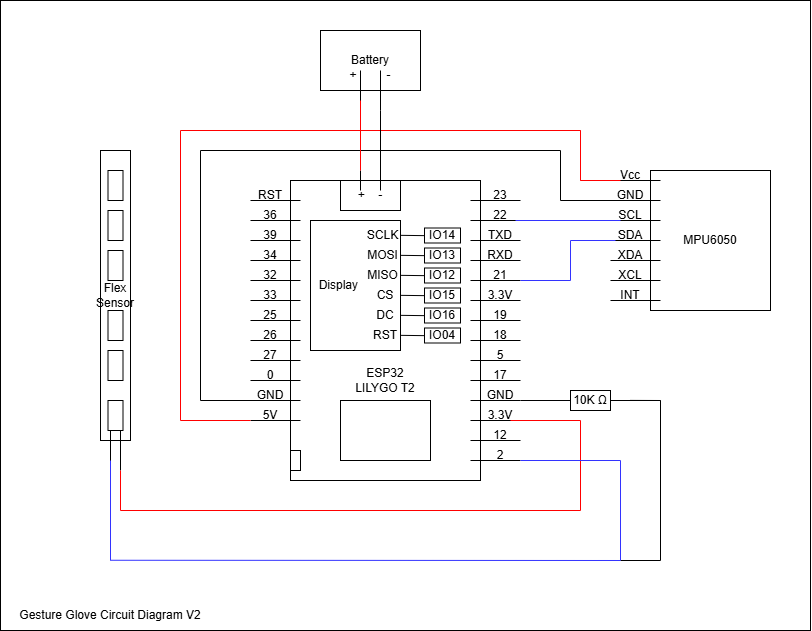
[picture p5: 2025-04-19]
Ontwerp/Elektrische schemas/Gesture Glove/electrical_circuit_v3.png

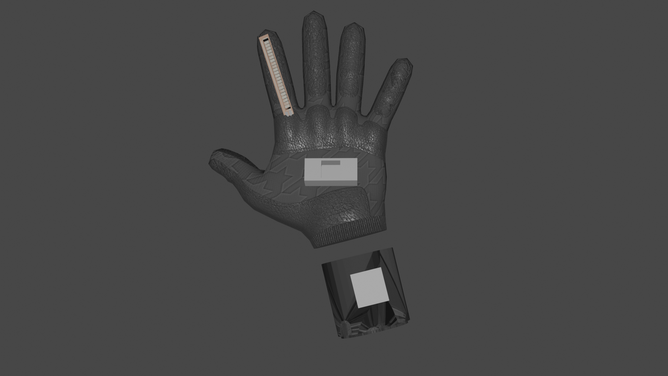
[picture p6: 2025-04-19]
Ontwerp/Gesture Glove/renderfinal.png

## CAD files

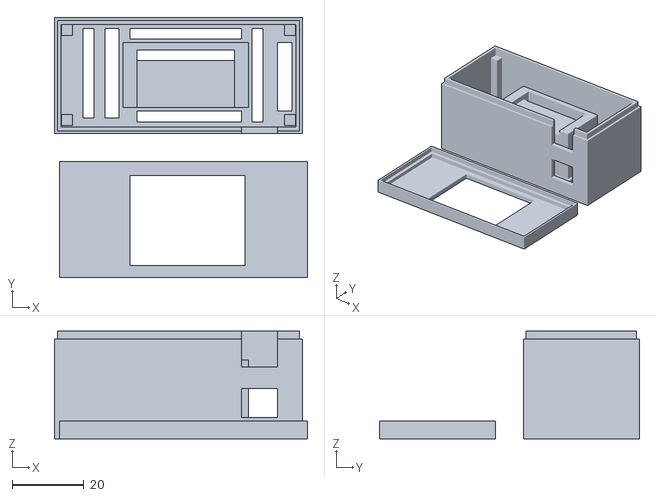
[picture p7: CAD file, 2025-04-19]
Ontwerp/Gesture Glove/box_design_v7.stl
70.4 x 72.3 x 30.0

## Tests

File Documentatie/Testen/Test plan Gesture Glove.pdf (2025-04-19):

## Test plan Gesture Glove

## Inleiding

Voor het testplan zijn er een aantal test onderdelen samengesteld. Ieder individuele component geeft zijn eigen testen gekregen, om zo zeker te zijn dat deze werkt. In dit document zijn alleen de testen te vonden zoals ze opgesteld zijn. De resultaten van deze testen zijn terug te vinden in het document testrapport. Deze testen zijn bedacht en uitgevoerd voor de Gesture Glove en zijn componenten.

## Testonderdelen

Test 1: ESP
Voor deze test wordt er gewerkt met de LiliGO TTGO T2 ESP32-WROOM. Het doel van de test is om te kijken of de LiliGO TTGO T2 ESP32-WROOM werkt wanneer aangesloten op een spanningsbron.
Testopstelling
Voor deze test wordt er gebruik gemaakt van een van een LiliGO TTGO T2 ESP32-WROOM.
Titel: | LiliGO TTGO T2 ESP32-WROOM
Requirement: | Wanneer de ESP aangesloten wordt op een spanningsbron gaat de ingebouwde LED van de ESP aan.
Omschrijving: | De ESP werkt, wat wordt aangeduid door de LED die gaat branden.
Stappenplan: | 1. Sluit de ESP aan op een spanningsbron/laptop. 2. Check of de LED van de ESP gaat branden.
Acceptance criteria | Wanneer de Led gaat branden is de test behaald.

Test 2: Button
Voor deze test wordt er gekeken of de button werkt voor de noodstop. Testopstelling
Voor deze test wordt er gebruik gemaakt van een van ESP32 en de button.
Titel: | Button
Requirement: | De stopknop laat het programma direct stoppen d.m.v. een hardware interrupt.
Omschrijving: | Wanneer op de stopknop gedrukt wordt, wordt de hardware interrupt getriggerd en komt het programma in een andere loop die werkzaamheden stopt.
Stappenplan: | 1. Druk op de knop 2. Check of in de seriële monitor geprint wordt dat de button ingedrukt is. 3. Check of de motoren direct stoppen met draaien en de display weergeeft dat het programma gestopt moet zijn.
Acceptance criteria | Wanneer er in de seriële monitor geprint wordt dat de button ingedrukt is, de motoren stoppen met draaien en de display het ook aangeeft.

Test 3: Auto
Voor deze test wordt er gewerkt met ‘de auto’. Deze auto bevat 4 motoren, een ESP32s en een L293D motor driver. De auto moet de gemeten sensor waardes van het hele project kunnen verwerken om zo zelfstandig te kunnen rijden.
Testopstelling
Voor deze testen moet de ESP32 aangesloten zijn aan de motoren. Voor de testen wordt gekeken of de auto kan rijden en of de ESP in staat is om een bluetooth verbinding te maken met de Gesture Glove om zo data binnen te krijgen.
Test 1
Voor deze test verbinden we alleen de motoren aan de ESP32.
Titel: | Motoren
Requirement: | De motoren kunnen alle richtingen in rijden door middel van een script.
Omschrijving: | De motoren kunnen draaien.
Stappenplan: | 1. Sluit de motoren aan op de ESP32 en de L293D chip 2. Run het script
Acceptance criteria | De motoren draaien zoals in het script aangegeven.

Test 2
Voor deze test moet de ESP32 van de auto kunnen communiceren met de ESP van de Gesture Glove, doormiddel van Bluetooth.
Titel: | ESP
Requirement: | De auto kan data ontvangen van de Gesture Glove, doormiddel van Bluetooth

Omschrijving: | De ESP van de auto heeft een Bluetooth connectie met de ESP van de Gesture Glove, om zo data te ontvangen.
Stappenplan: | 1. Start de ESP van de Gesture Glove 2. Start de auto 3. Check in de seriële monitor of er data ontvangen wordt van de Gesture Glove
Acceptance criteria | De auto ontvangt data van de Gesture Glove

Test 4: IMU
Voor deze test wordt er gewerkt met een IMU-sensor. Deze sensor moet meerdere onderdelen meten. Het gaat hierbij om de acceleratie en de gyroscoop waardes. Daarnaast is er ook een optie om de temperatuur te kunnen meten.
Testopstelling
Voor deze test wordt er gebruik gemaakt van een ESP32 en een IMU-sensor. De IMU-sensor moet de beweging van je hand meten.
Test 1
Voor deze test wordt er gekeken of de IMU-sensor de Acceleration kan meten. Hiervoor wordt alleen de sensor aangesloten.
Titel: | IMU Acceleration
Requirement: | Verschillende bewegingen moeten gedetecteerd kunnen worden op de X, Y en Z as. Het gaat hierbij om verschuiving.
Omschrijving: | Wanneer je je hand beweeg wordt er data gestuurd naar de seriële monitor. Hierin kan je lezen wat de X, Y en Z waardes zijn.
Stappenplan: | 1. Sluit de sensor aan 2. Beweeg je hand 3. Check of de bewegingen gedetecteerd worden
Acceptance criteria | De juiste bewegingen moeten gedetecteerd worden en geprint in de seriële monitor.

Test 2
Voor deze test worst er gekeken of de gyroscoop van de IMU-data kan meten. Hiervoor wordt alleen de sensor aangesloten.
Titel: | IMU Gyroscoop
Requirement: | Verschillende bewegingen moeten gedetecteerd kunnen worden. Het gaat hierbij om het kantelen van je hand.

Omschrijving: | Wanneer je je hand beweeg wordt er data gestuurd naar de seriële monitor.
Stappenplan: | 1. Sluit de sensor aan 2. Beweeg je hand 3. Check of de bewegingen gedetecteerd worden
Acceptance criteria | De juiste bewegingen moeten gedetecteerd worden en geprint in de seriële monitor.

Test 3
Voor deze test worst er gekeken of gyroscoop van de IMU-sensor actuele data kan meten en teruggeven.
Titel: | IMU Gyroscoop
Requirement: | De gyroscoop meet accurate data.
Omschrijving: | Wanneer je je hand beweeg wordt er data gestuurd naar de seriële monitor. Wanneer je de sensor 90 graden draait, krijg je deze waarde terug.
Stappenplan: | 1. Sluit de sensor aan 2. Plaats de sensor tegen een recht oppervlak 3. Controller of de gemeten data overeenkomen met de verwachtingen.
Acceptance criteria | De gemeten waardes mogen niet te veel schelen van de verwachte data.

Test 4
Voor deze test worst er gekeken of de acceleratie sensor van de IMU-sensor juiste waardes teruggeeft. Voor deze test is een extra Python bestand nodig.
Titel: | IMU Gyroscoop
Requirement: | De IMU-sensor geeft de juiste acceleratie waardes terug
Omschrijving: | Om duidelijk te kunnen zien of de beweging die de IMU-sensor meet overeenkomt met de daadwerkelijke waardes is er een extra visualisatie stap toegevoegd. Een python programma visualiseert een blokje die beweegt in dezelfde richting als je hand.
Stappenplan: | 1. Sluit de sensor aan 2. Beweeg je hand 3. Controleer doormiddel van het Python programma of de gegevens overeenkomen
Acceptance criteria | Het blokje moet dezelfde richting in bewegen als de IMU-sensor.

Test 5
Voor deze test worst er gekeken of de gyroscoop van de IMU-sensor werkt met een PID-systeem erin verwerkt.
Titel: | IMU Gyroscoop
Requirement: | Het PID-systeem verwerkt de gyroscoop data en maakt de data vloeiender.
Omschrijving: | Wanneer je je hand beweeg wordt er data gestuurd naar de seriële plotter. In de plotter kan je een overshoot zien door de PID.

Stappenplan: | 4. Sluit de sensor aan 5. Beweeg je hand 6. Controleer in de seriële plotter of er een overshoot is, en de PID dus werkt.
Acceptance criteria | Het PID-systeem moet juist geïmplementeerd zijn.

Test 5: Display
Voor deze test wordt er gekeken of de display van de ESP32 werkt. Er wordt getest of er op de display geprint kan worden
Testopstelling
Voor deze test wordt er gebruik gemaakt van een ESP32 en een OLED-display scherm.
Titel: | Werkende OLED
Requirement: | Op de display worden alle functies van de GFX adafruit library getoond.
Omschrijving: | Wanneer de code gerund wordt, moet er op de OLED display de functies om de paar seconden te zien zijn.
Stappenplan: | 1. Run de code 2. Check of alle functies naar behoren werken
Acceptance criteria | De display moet alle functies naar behoren laten zien. Voorbeelden zijn: een kubus of cirkel printen, alleen de outline of gevuld, tekst printen.

Test 2:
Titel: | Timing OLED
Requirement: | De totale tijd van het updaten van recente waarde duurt niet langer dan 50 ms
Omschrijving: | Er worden verschillende functies om de display te updaten getest op tijdconsumptie. Daar wordt de meest efficiënte manier gekozen om de display zo realtime mogelijk te houden.

Stappenplan: | 1. Run de code 2. Check hoeveel tijd elke functie in beslag neemt met behulp van millis (); 3. Kies de meest efficiënte maar duidelijke combinatie
Acceptance criteria | De totale tijd dat de display er over doet om de reëel sensordata weer te geven duurt niet meer dan 50 ms.

Test 6: Flex sensor
Voor dit onderdeel wordt er getest met de Flex sensor.
Testopstelling
Voor deze test wordt er gebruik gemaakt van een ESP32 en een Flex sensor.
Titel: | Flex sensor
Requirement: | Een Flex sensor kan zien of de hand in een vuist veranderd wordt.
Omschrijving: | De test evalueert de nauwkeurigheid en van de Flex sensor bij het detecteren van vingerbewegingen Bevestig de Flex sensor aan de binnenkant van de hand aan de wijsvinger. Verbind de Flex sensor met de ADC-ingang van de ESP32. Flash de volgende code naar de esp32: #include <Arduino.h> #define ADC_PIN 36 // GPIO36 (VP) on ESP32 void setup() { Serial.begin(115200); analogReadResolution(12); // Set ADC resolution to 12-bit } void loop() { int raw_value = analogRead(ADC_PIN); if(raw_value > 2700){ Serial.printf("Fist Detected"); } delay(500); // Delay 500ms }
Stappenplan: | 1. Start met een open hand en volledig gestrekte vingers.
2. Buig de vingers geleidelijk tot een vuist over een periode van 5
| seconden.
3. Laat de hand weer volledig ontspannen naar de startpositie.
4. Herhaal de beweging meerdere keren.

Acceptance
criteria

De seriële monitor moet in alle gevallen waar een vuist gemaakt wordt de tekst: “Fist Detected” weergeven

## ChangeLog

ChangeLog
Versie | Datum | Wijziging
0.1 | 19-03-2025 | Document aangemaakt
0.2 | 03-04-2025 | Testen IMU toegevoegd
0.3 | 09-04-2025 | Test Flex toegevoegd
0.4 | 11-04-2025 | Auto test toegevoegd
0.5 | 14-04-2025 | ESP test toegevoegd
1.0 | 14-04-2025 | Overbodige informatie verwijderd

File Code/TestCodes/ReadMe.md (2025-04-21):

## Testbestanden

In deze map staan drie testbestanden. Deze zijn gebruikt tijdens het maken van de Gesture Glove en voor het uitvoeren van de testen zoals beschreven in het testplan en testrapport.

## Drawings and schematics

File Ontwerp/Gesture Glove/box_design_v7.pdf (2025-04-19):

2
1

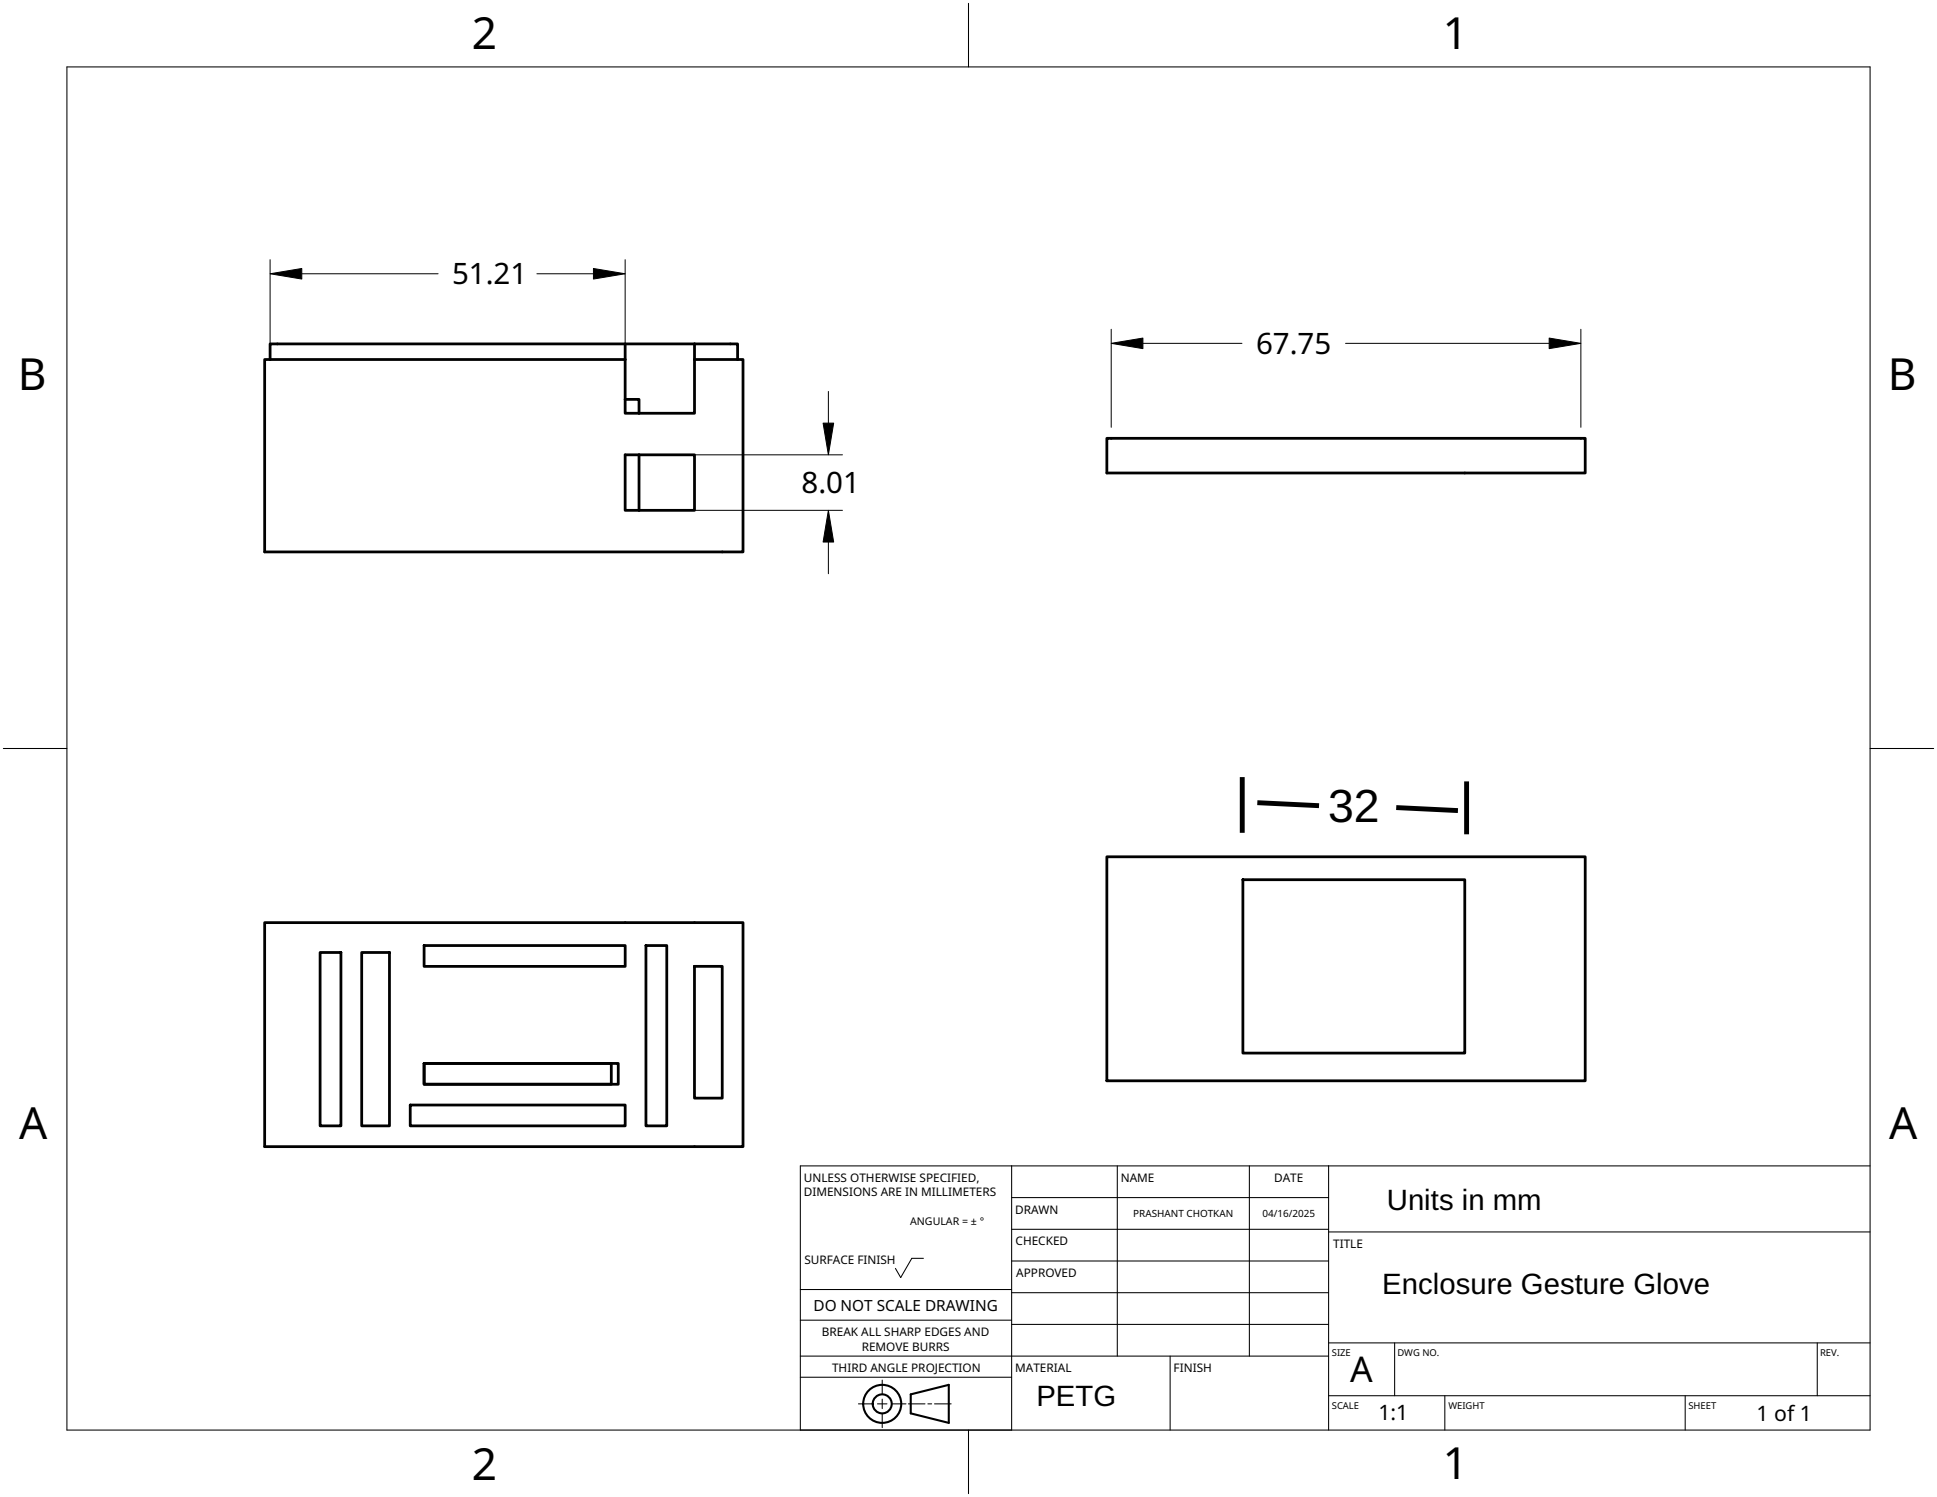
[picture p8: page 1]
MATERIAL; FINISH

UNLESS OTHERWISE SPECIFIED, DIMENSIONS ARE IN MILLIMETERS ANGULAR = ± ° SURFACE FINISH | | NAME | DATE

DRAWN | PRASHANT CHOTKAN | 04/16/2025

CHECKED | | | TITLE

APPROVED

DO NOT SCALE DRAWING

BREAK ALL SHARP EDGES AND

REMOVE BURRS
THIRD ANGLE PROJECTION

SIZE A | DWG NO. | REV.

SCALE 1:1 | WEIGHT | SHEET 1 of 1

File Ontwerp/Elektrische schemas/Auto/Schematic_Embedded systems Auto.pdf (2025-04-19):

## VCC

DC

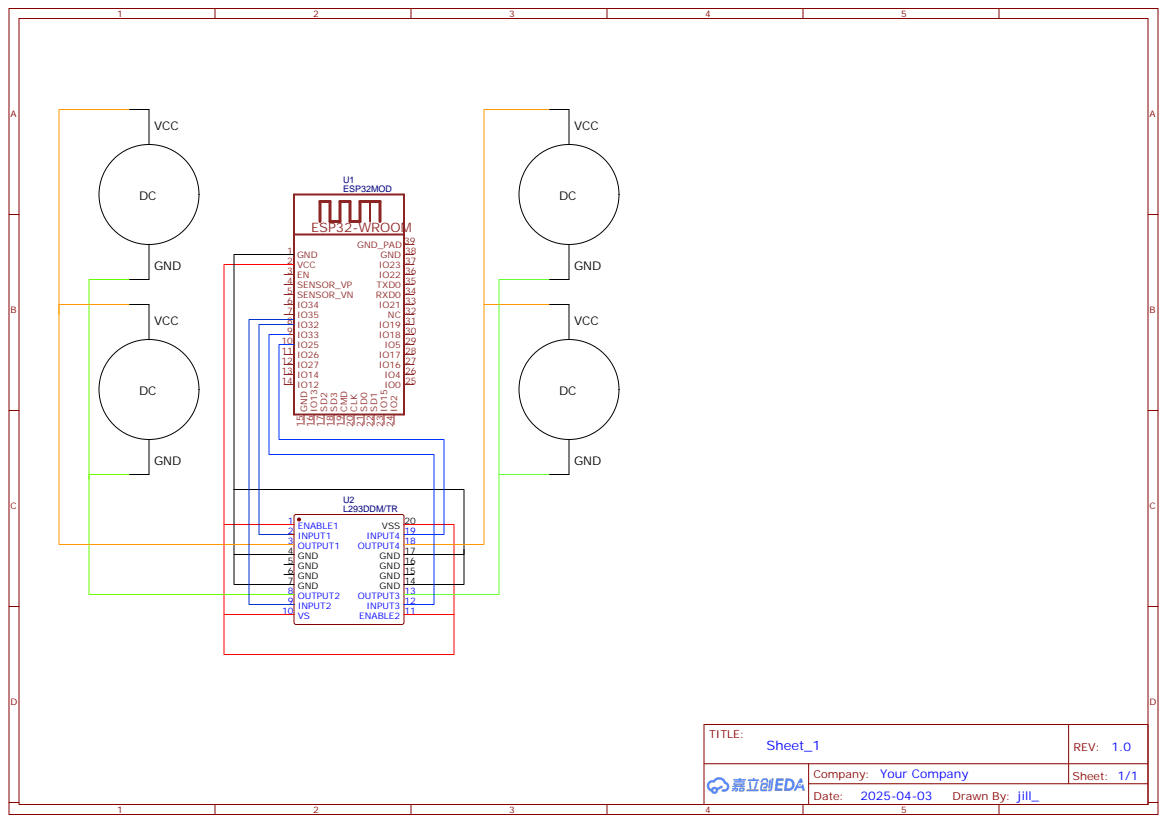
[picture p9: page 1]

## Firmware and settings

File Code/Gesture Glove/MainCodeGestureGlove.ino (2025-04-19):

#include <Adafruit_GFX.h>//////////////////////////////////////////////////////////////////////////////////////
#include <Adafruit_SSD1331.h>//////////////////////////////////////////////////////////////////////////////////
#include <SPI.h>/////////////////////////////////FINAL/////////////////////////////////////////////////////////
#include <MPU6500_WE.h>////////////////////////////////////////////////////////////////////////////////////////
#include <Wire.h>//////////////////////////////////////////////////////////////////////////////////////////////
#include "esp_task_wdt.h"
#include <BLEDevice.h>
#include <BLEUtils.h>
#include <BLEServer.h>
#include <BLE2902.h>
#include <Ticker.h>

///// Pin and Device Configuration /////
// Display pins
const uint8_t sclk = 14;   // Serial clock pin
const uint8_t mosi = 13;   // Master Out Slave In pin
const uint8_t cs = 15;     // Chip Select pin
const uint8_t dc = 16;     // Data/Command pin
const uint8_t rst = 4;     // Reset pin

// IMU pins
const uint8_t scl = 22;    // I2C clock pin for IMU
const uint8_t sda = 21;    // I2C data pin for IMU
const uint8_t addr = 0x68; // I2C address for MPU6500

// Input pins
const uint8_t button = 36; // Onboard button pin
const uint8_t flex = 2;    // Analog pin for flex sensor
const uint8_t battery = 35;// Analog pin for battery voltage

// Watchdog timeout setting
const int wdtTimeoutMs = 100;  // Reset if no response in 5 seconds

///// Threshold Configuration /////
// IMU tresholds
const int imuActive = 20;    // Minimum value to detect movement
const int imuDeadZone = 15;  // Value below which movement is ignored
const int rawPrintThreshold = 10; // Minimum change before printing raw values

///// PID Controller Configuration /////
float kp = 0.6;       // Proportional gain
float ki = 0.1;       // Integral gain
float kd = 0.005;     // Derivative gain
float lastErrorX = 0; // Previous X error for derivative term
float lastErrorY = 0; // Previous Y error for derivative term
float integralX = 0;  // Accumulated X error for integral term
float integralY = 0;  // Accumulated Y error for integral term
float integralLimit = 100.0; // Limit to prevent integral windup

///// Angle Tracking /////
// IMU angle variables
float rawX = 0.0;     // Raw X angle from integration
float rawY = 0.0;     // Raw Y angle from integration
float pidX = 0.0;// PID-filtered X angle
float pidY = 0.0;// PID-filtered Y angle
int lastPrintX = 0;   // Last printed X value
int lastPrintY = 0;   // Last printed Y value

///// Timing Configuration /////
// Ticker object for slow data updates
Ticker slowDataTicker;

// Flag to indicate when a slow data update should occur
volatile bool slowDataFlag = false;

unsigned long lastUpdate = 0; // Last sensor update time

// State tracking
bool hwStopClicked = false;  // Tracks if hardware stop button was pressed

///// Connection /////
#define DEVICE_NAME "GloveESP32"
#define SERVICE_UUID        "4fafc201-1fb5-459e-8fcc-c5c9c331914b"
#define CHARACTERISTIC_UUID "beb5483e-36e1-4688-b7f5-ea07361b26a8"

BLEServer* pServer = nullptr;
BLECharacteristic* pCharacteristic = nullptr;
bool deviceConnected = false;
bool oldDeviceConnected = false;

esp_bd_addr_t clientAddress;
int rssiValue = 0;

///// Data structures /////
// Structure for real-time sensor readings
struct SensorData {
  float gyroX, gyroY, gyroZ;  // IMU gyroscope readings
  uint8_t flexValue;          // Flex sensor reading (0-100%)
};

// Structure for slow-updating status data
struct SlowData {
  uint8_t gloveBat;     // Glove battery level (0-100%)
  uint8_t endBat;       // End device battery level (0-100%)
  uint8_t bleStrength;  // Bluetooth connection strength (0-100%)
  uint8_t endSpeed;     // End device speed (0-100%)
};

// Device orientation enum with bit flags for multi-direction support
enum Orient {
  CENTER   = 0,         // No movement detected
  FORWARD  = 1 << 0,    // Forward movement
  BACKWARD = 1 << 1,    // Backward movement
  LEFT     = 1 << 2,    // Left movement
  RIGHT    = 1 << 3     // Right movement
};

// Current state of the ESP controller
struct EspState {
  bool braking;         // True when braking is active
  bool stopped;         // True when device is stopped
  uint8_t orientation;  // Current orientation (can combine multiple directions)
};  

// Initialize current state
EspState curState = {false, false, CENTER}; // Can use combined values like (FORWARD | LEFT)

///// Task and queue handles /////
TaskHandle_t SensorTask;    // Handle for sensor reading task
TaskHandle_t DataTask;      // Handle for data processing task
QueueHandle_t sensorQueue;  // Queue for passing sensor data between tasks

///// Object initialization /////
// Initialize display
Adafruit_SSD1331 display = Adafruit_SSD1331(cs, dc, mosi, sclk, rst);
// Initialize IMU
MPU6500_WE myMPU6500 = MPU6500_WE(addr);

///// UI Icons - 8x10 bitmap arrays /////
// Battery indicator icon
const uint8_t batteryIcon[] = {
  0b00111000,
  0b01111100,  
  0b10000010,  
  0b10111010,  
  0b10111010,
  0b10111010,
  0b10111010,
  0b10111010, 
  0b10000010,  
  0b01111100
};

// Glove indicator icon
const uint8_t gloveIcon[] = {
  0b00001000,
  0b00101010,
  0b00101010,
  0b10101010,
  0b10111101,
  0b10111101,
  0b11111111,
  0b11111111,
  0b01111110,
  0b00111100
};

// Wheel indicator icon
const uint8_t wheelIcon[] = {
  0b00111100,
  0b01100110,
  0b11000011,
  0b11100111,
  0b10111101,
  0b10011001,
  0b10011001,
  0b11011011,
  0b01111110,
  0b00111100
};

// Stop indicator icon
const uint8_t stoppedIcon[] = {
  0b11000011,
  0b01100110,
  0b01111110,
  0b00111100,
  0b00011100,
  0b00011100,
  0b00111100,
  0b01111110,
  0b11100111,
  0b11000011
};

// Connection indicator icon
const uint8_t connectionIcon[] = {
  0b00000011,
  0b00000011,  
  0b00000011,  
  0b00011011,  
  0b00011011,
  0b00011011,
  0b11011011,
  0b11011011, 
  0b11011011,  
  0b11011011
};

// Speed indicator icon
const uint8_t speedIcon[] = {
  0b00000000,
  0b00000000,  
  0b00011000,  
  0b00100100,  
  0b01000110,
  0b01001110,
  0b01011010,
  0b1001001, 
  0b10000001,
  0b10000001
};

///// Function declarations /////
void sensebuttonPressed();
void handlePossibleSleep();
void gapCallback(esp_gap_ble_cb_event_t event, esp_ble_gap_cb_param_t *param);
void sendBleData(BLECharacteristic* ptr_characteristic, const char* message);
SlowData readSlowData();
float pidController(float target, float current, float &lastError, float &integral);
SensorData readSensors();
void sensorTaskLoop(void * pvParameters);
void displayBLEConnect();
void displayLayout();
void displayFastData(SensorData data);
void displaySlowData(SlowData sData);
void sendData(SensorData data);
void dataTaskLoop(void * pvParameters);

///// Power Management Functions and Interrupts /////

/**
 * Interrupt service routine for onboard button press
 * Toggles the stopped state and sets the hwStopClicked flag
 */
void sensebuttonPressed() {
  hwStopClicked = true;
  curState.stopped = !curState.stopped;
}

/**
 * Handles sleep logic after device has been stopped
 * Waits for 5 seconds before going to sleep if no other input is received
 */
void handlePossibleSleep() {
  sendBleData();
  const int waitMs = 5000;    // Wait 5 seconds before sleep
  const int interval = 100;   // Check every 100ms
  int waited = 0;

  // Update UI to show sleep pending
  display.fillRect(66, 3, 11, 7, 0x0000);
  display.setCursor(66, 3);
  display.print("yes");
  display.fillCircle(73, 42, 19, 0x0000);
  display.fillCircle(73, 42, 10, 0xF800);
  curState.braking = true;
  hwStopClicked = false;

  // Wait loop with early exit if button pressed again
  while (waited < waitMs) {
    if (hwStopClicked == true) {
      hwStopClicked = false;  // reset flag
      display.fillRect(66, 3, 17, 8, 0x0000);
      display.setCursor(66, 3);
      display.print("no");
      return;  // button pressed again - don't sleep
    }
    esp_task_wdt_reset();  // Reset watchdog timer
    vTaskDelay(interval / portTICK_PERIOD_MS);
    waited += interval;
  }

  // If still stopped after timeout, go to deep sleep
  if (curState.stopped == true) {
    display.fillScreen(0x0000); // Clear before sleep
    display.setCursor(40, 30);
    display.print("Going to sleep...");
    delay(500);
    esp_task_wdt_deinit();  // Disable watchdog before sleep
    // Configure wakeup on button press
    esp_sleep_enable_ext0_wakeup((gpio_num_t)button, 0);
    esp_deep_sleep_start();  // Enter deep sleep mode
  }
  esp_task_wdt_reset();
}

/**
 * Software interupt handler
 */
void triggerSlowDataUpdate() {
  slowDataFlag = true;
}

// BLE Callbacks
class MyServerCallbacks : public BLEServerCallbacks {
  void onConnect(BLEServer* pServer, esp_ble_gatts_cb_param_t* param) {
    deviceConnected = true;
    memcpy(clientAddress, param->connect.remote_bda, sizeof(esp_bd_addr_t));
    Serial.println("Device connected");
  }

  void onDisconnect(BLEServer* pServer) {
    deviceConnected = false;
    Serial.println("Device disconnected");
  }
};

/**
 * Measures BLE strength
 */
void gapCallback(esp_gap_ble_cb_event_t event, esp_ble_gap_cb_param_t *param) {
  if (event == ESP_GAP_BLE_READ_RSSI_COMPLETE_EVT) {
    rssiValue = param->read_rssi_cmpl.rssi;
    int strength = map(rssiValue, -100, -40, 0, 100);
    strength = constrain(strength, 0, 100);
    Serial.printf("RSSI: %d dBm (%d%%)\n", rssiValue, strength);
    Serial.print("Signal: [");
    for (int i = 0; i < 10; i++) {
      Serial.print(i < strength / 10 ? "=" : " ");
    }
    Serial.println("]");
  }
}

///// Bluetooth Functions /////

/**
 * Sends the sensor data over BLE to connected devices
 */
void sendBleData() {
  if (deviceConnected) {
    static char buffer[11]; // 8 chars for orientation + 2 chars for states + null
    
    // First two chars for braking and stopped
    buffer[0] = curState.stopped ? '1' : '0';
    buffer[1] = curState.braking ? '1' : '0';
    Serial.println(curState.stopped);
    Serial.println(buffer[0]);
    
    // Next 8 chars for orientation as a binary representation
    for (int i = 0; i < 8; i++) {
      buffer[2+i] = (curState.orientation & (1 << (7-i))) ? '1' : '0';
    }
    buffer[10] = '\0'; // Null terminator 

    pCharacteristic->setValue(buffer);
    pCharacteristic->notify();
  }
}

///// Sensor Functions /////

/**
 * Measures all less critical data like battery and connections status
 * Currently only the BLE strength status works
 */
SlowData readSlowData() {
  SlowData sData;
  
  // Calculate battery percentage from voltage reading
  float minVolt = 3.2;  // Minimum battery voltage
  float maxVolt = 4.2;  // Maximum battery voltage
  float voltage = analogRead(battery);
  int percent = ((voltage - minVolt) / (maxVolt - minVolt)) * 100;
  sData.gloveBat = constrain(percent, 0, 100); // Ensure value is between 0-100%
  
  // Update BLE strength using RSSI
  esp_ble_gap_read_rssi(clientAddress); // Request RSSI
  int strength = map(rssiValue, -100, -40, 0, 100); // Clearer indicator for most people
  sData.bleStrength = constrain(strength, 0, 100); // BLE signal strength
  
  // Placeholder values
  sData.endBat = 98;    // End device battery // Not integrated yet
  sData.endSpeed = 1;    // End device speed   // Not integrated yet
  
  return sData;
}

/**
 * PID controller function for smoothing sensor data
 * 
 * @param target The target value (usually 0 for IMU drift compensation)
 * @param current The current sensor reading
 * @param lastError Reference to store last error value
 * @param integral Reference to store integral term
 * @return The PID-filtered output value
 */
float pidController(float target, float current, float &lastError, float &integral) {
  float error = target - current;  // Calculate error

  // Reset integral if error is small to prevent oscillation
  if (fabs(error) < 10) {
    integral = 0;
  } else {
    integral += error;
  }

  // Constrain the integral to avoid wind-up
  integral = constrain(integral, -integralLimit, integralLimit);

  float derivative = error - lastError;  // Calculate derivative
  lastError = error;  // Update last error

  // Calculate the PID output and invert the sign
  float pidOutput = kp * error + ki * integral + kd * derivative;

  // Flip the sign of the PID output
  return -pidOutput;
}

/**
 * Reads all sensor data and applies filtering
 * @return SensorData structure with processed readings
 */
SensorData readSensors() {
  SensorData data;
  
  // Read flex sensor and convert to percentage
  data.flexValue = (analogRead(flex) / 3200.0) * 100;
  Serial.print("flex reading: ");
  Serial.println(data.flexValue);
  
  // Read raw gyroscope values
  xyzFloat gyrValue = myMPU6500.getGyrValues();

  // Apply PID filtering to the gyroscope values
  float pidGyrX = pidController(0.0, gyrValue.x, lastErrorX, integralX);
  float pidGyrY = pidController(0.0, gyrValue.y, lastErrorY, integralY);

  // Calculate time delta for angle integration
  unsigned long currentTime = millis();
  float dt = (currentTime - lastUpdate) / 1000.0;  // Time difference in seconds
  lastUpdate = currentTime;  // Update last update time

  // Integrate raw angles using gyroscope values
  rawX += gyrValue.x * dt;
  rawY += gyrValue.y * dt;

  // Integrate PID-filtered angles
  pidX += pidGyrX * dt;
  pidY += pidGyrY * dt;

  // Constrain angles to ±90 degrees to prevent unrealistic values
  rawX = constrain(rawX, -90.0, 90.0);
  rawY = constrain(rawY, -90.0, 90.0);
  pidX = constrain(pidX, -90.0, 90.0);
  pidY = constrain(pidY, -90.0, 90.0);

  // Smoothly reduce PID values when raw angles approach zero
  float smoothingFactor = 0.1;  // How quickly PID values decay to zero

  if (fabs(rawX) < 1.0) {  // If X is close to zero
    pidX *= (1 - smoothingFactor);  // Gradually decay PID X value
  }

  if (fabs(rawY) < 1.0) {  // If Y is close to zero
    pidY *= (1 - smoothingFactor);  // Gradually decay PID Y value
  }

  // Round values to integers for display and debugging
  int rawIntX = round(rawX);
  int rawIntY = round(rawY);
  int pidIntX = round(pidX);
  int pidIntY = round(pidY);

  // Check if the raw data has changed enough to print (reduces console spam)
  bool rawChanged = abs(rawIntX - lastPrintX) >= rawPrintThreshold ||
                    abs(rawIntY - lastPrintY) >= rawPrintThreshold;

  if (rawChanged) {
    // Snap to nearest multiple of 10 for raw data
    rawIntX = (rawIntX / 10) * 10;
    rawIntY = (rawIntY / 10) * 10;

    // Update last printed values
    lastPrintX = rawIntX;
    lastPrintY = rawIntY;
  }

  // Always print PID data for debugging
  Serial.print("PIDX: "); 
  Serial.print(pidIntX); 
  Serial.print("\t");
  Serial.print("PIDY: "); 
  Serial.println(pidIntY);
  
  // Store filtered values in the result structure
  data.gyroX = pidIntX;
  data.gyroY = pidIntY;
  
  return data;
}

/**
 * FreeRTOS task for continuous sensor polling
 * Runs on core 0 and sends data to the queue for processing
 */
void sensorTaskLoop(void * pvParameters) {
  esp_task_wdt_add(NULL);  // Register task to watchdog
  
  while(true) {
    SensorData data = readSensors();  // Read sensor data
    
    // Send data to queue with 50ms timeout
    BaseType_t status = xQueueSend(sensorQueue, &data, pdMS_TO_TICKS(50));
    
    if (status != pdPASS) {
      // Display there is a delay or fault between the sensors and display
      Serial.println("Data was measured but not sent to the display");
    }
    
    esp_task_wdt_reset();  // Reset watchdog timer
  }
}

///// Display and UI Functions /////

/**
 * Draws the initial display layout with all UI elements
 * Should be called everytime before starting to display sensor data
 */
void displayLayout() {
  display.fillScreen(0x0000); // Black background
  
  // Layout divider lines
  display.drawFastVLine(50, 0, 64, 0xFFFF);  // Vertical divider
  display.drawFastHLine(0, 32, 50, 0xFFFF);  // Left section horizontal divider
  display.drawFastHLine(50, 20, 46, 0xFFFF); // Right section top divider
  
  // Gyroscope visualization elements
  display.drawCircle(73, 42, 20, 0xFFFF);   // Outer circle
  display.fillCircle(73, 42, 2, 0x07E0);    // Inner circle (green indicator)
  
  // Status icons and labels for left panel
  display.drawBitmap(1, 3, batteryIcon, 8, 10, 0xFFFF);    // Glove battery icon
  display.drawBitmap(10, 3, gloveIcon, 8, 10, 0xFFFF);     // Glove icon
  display.setCursor(19, 5);
  display.print(":");                                      // Separator
  
  display.drawBitmap(1, 35, batteryIcon, 8, 10, 0xFFFF);   // End device battery icon
  display.drawBitmap(10, 35, wheelIcon, 8, 10, 0xFFFF);    // Wheel icon
  display.setCursor(19, 37);
  display.print(":");                                      // Separator
  
  display.drawBitmap(1, 16, connectionIcon, 8, 10, 0xFFFF); // Connection icon
  display.setCursor(10, 18);
  display.print(":");                                       // Separator
  
  display.drawBitmap(1, 48, speedIcon, 8, 10, 0xFFFF);      // Speed icon
  display.setCursor(10, 50);
  display.print(":");                                       // Separator
  
  // Status icons and labels for right panel
  display.drawBitmap(52, 3, stoppedIcon, 8, 10, 0xFFFF);    // Stop icon
  display.setCursor(61, 5);
  display.print(":");                                       // Separator
}

/**
 * Shows when the esp is advertising its bluetooth
 */
void displayBLEConnect(){
  display.fillScreen(0x0000); // Clear before sleep
  display.setCursor(1, 25);
  display.print("Searching for  bluetooth...");
}

/**
 * Updates the display with rapidly changing sensor data
 * Shows brake status and direction indicators
 * 
 * @param data Current sensor readings to display
 */
void displayFastData(SensorData data) {
  // Check for coming out of stop state
  if (hwStopClicked == true) {
    display.fillRect(66, 3, 17, 8, 0x0000);  // Clear previous text
    display.setCursor(66, 3);
    display.print("no");                     // Update stop indicator
    hwStopClicked = false;
  }
  
  // Display flex sensor activation (brake control)
  if (data.flexValue <= 30 && curState.braking == true) {
    // Release brake
    display.fillCircle(73, 42, 10, 0x0000);        // Clear brake indicator
    display.fillCircle(73, 42, 5, 0x07E0);         // Show green "go" indicator
    curState.braking = false;
  } else if (data.flexValue > 30 && curState.braking == false) {
    // Apply brake
    display.fillCircle(73, 42, 10, 0xF800);        // Show red "brake" indicator
    curState.braking = true;
  }
  
  // Handle forward/backward direction indicators
  if (data.gyroY < -imuActive && !(curState.orientation & FORWARD)) {
    // Draw forward and delete backward indicators
    display.fillCircle(73, 57, 4, 0x0000);        // Clear bottom indicator
    display.fillCircle(73, 27, 4, 0xFFFF);        // Show top indicator
    curState.orientation |= FORWARD;              // Add FORWARD flag
    curState.orientation &= ~BACKWARD;            // Remove BACKWARD flag if active
    curState.orientation &= ~CENTER;              // Remove CENTER flag
  }
  else if (data.gyroY > imuActive && !(curState.orientation & BACKWARD)) {
    // Draw backward and delete forward indicators
    display.fillCircle(73, 27, 4, 0x0000);        // Clear top indicator
    display.fillCircle(73, 57, 4, 0xFFFF);        // Show bottom indicator
    curState.orientation |= BACKWARD;             // Add BACKWARD flag
    curState.orientation &= ~FORWARD;             // Remove FORWARD flag if active
    curState.orientation &= ~CENTER;              // Remove CENTER flag
  }
  else if (abs(data.gyroY) < imuDeadZone) {
    // Clear both forward/backward indicators when in deadzone
    display.fillCircle(73, 27, 4, 0x0000);        // Clear top indicator
    display.fillCircle(73, 57, 4, 0x0000);        // Clear bottom indicator
    curState.orientation &= ~FORWARD;             // Remove FORWARD flag
    curState.orientation &= ~BACKWARD;            // Remove BACKWARD flag
  }
  
  // Handle left/right direction indicators
  if (data.gyroX > imuActive && !(curState.orientation & LEFT)) {
    // Draw left and delete right indicators
    display.fillCircle(88, 42, 4, 0x0000);        // Clear right indicator
    display.fillCircle(58, 42, 4, 0xFFFF);        // Show left indicator
    curState.orientation |= LEFT;                 // Add LEFT flag
    curState.orientation &= ~RIGHT;               // Remove RIGHT flag if active
    curState.orientation &= ~CENTER;              // Remove CENTER flag
  }
  else if (data.gyroX < -imuActive && !(curState.orientation & RIGHT)) {
    // Draw right and delete left indicators
    display.fillCircle(58, 42, 4, 0x0000);        // Clear left indicator
    display.fillCircle(88, 42, 4, 0xFFFF);        // Show right indicator
    curState.orientation |= RIGHT;                // Add RIGHT flag
    curState.orientation &= ~LEFT;                // Remove LEFT flag if active
    curState.orientation &= ~CENTER;              // Remove CENTER flag
  }
  else if (abs(data.gyroX) < imuDeadZone) {
    // Clear both left/right indicators when in deadzone
    display.fillCircle(58, 42, 4, 0x0000);        // Clear left indicator
    display.fillCircle(88, 42, 4, 0x0000);        // Clear right indicator
    curState.orientation &= ~LEFT;                // Remove LEFT flag
    curState.orientation &= ~RIGHT;               // Remove RIGHT flag
  }
  
  // Handle CENTER case (no active directions)
  if (curState.orientation == 0) {
    // All directions are already cleared in the deadzone checks above
    curState.orientation = CENTER;                // Set CENTER flag
  }
  else if (curState.orientation != CENTER) {
    // Make sure CENTER is not mixed with active directions
    curState.orientation &= ~CENTER;              // Remove CENTER flag
  }
}
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
void loop() {
  // Nothing to do here - all functionality is in FreeRTOS tasks
}

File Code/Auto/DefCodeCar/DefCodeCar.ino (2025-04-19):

// Includes //
#include <BLEDevice.h>
#include <BLEUtils.h>
#include <BLEClient.h>
#include <stdint.h>
#include <stdbool.h>

// BLE Data //
#define SERVICE_UUID        "4fafc201-1fb5-459e-8fcc-c5c9c331914b"
#define CHARACTERISTIC_UUID "beb5483e-36e1-4688-b7f5-ea07361b26a8"
#define BLE_SERVER_MAC      "08:3A:F2:59:B8:D2"

// Motor Pins //
const int output1 = 25;    
const int output2 = 26;    
const int output3 = 14;    
const int output4 = 13;    

// BLE Data //
BLEClient* pClient;
BLERemoteService* pRemoteService;
BLERemoteCharacteristic* pRemoteCharacteristic;

bool connected = false;
unsigned long lastReceivedTime = 0;
const unsigned long timeout = 5000;  // in ms

// Motor control functions //
void forward() {
  digitalWrite(output1, HIGH);      
  digitalWrite(output2, LOW);       
  digitalWrite(output3, HIGH);      
  digitalWrite(output4, LOW);       
}

void backward() {
  digitalWrite(output1, LOW);
  digitalWrite(output2, HIGH);
  digitalWrite(output3, LOW);
  digitalWrite(output4, HIGH);
}

void backwardLeft() {
  digitalWrite(output1, LOW);
  digitalWrite(output2, HIGH);
  digitalWrite(output3, LOW);
  digitalWrite(output4, LOW);
}

void backwardRight() {
  digitalWrite(output1, LOW);
  digitalWrite(output2, LOW);
  digitalWrite(output3, LOW);
  digitalWrite(output4, HIGH);
}

void left() {
  digitalWrite(output1, LOW);
  digitalWrite(output2, LOW);
  digitalWrite(output3, HIGH);
  digitalWrite(output4, LOW);
}

void leftSharp() {
  digitalWrite(output1, LOW);
  digitalWrite(output2, HIGH);
  digitalWrite(output3, HIGH);
  digitalWrite(output4, LOW);
}

void right() {
  digitalWrite(output1, HIGH);
  digitalWrite(output2, LOW);
  digitalWrite(output3, LOW);
  digitalWrite(output4, LOW);
}

void rightSharp() {
  digitalWrite(output1, HIGH);
  digitalWrite(output2, LOW);
  digitalWrite(output3, LOW);
  digitalWrite(output4, HIGH);
}

void stopMotors() {
  digitalWrite(output1, LOW);
  digitalWrite(output2, LOW);
  digitalWrite(output3, LOW);
  digitalWrite(output4, LOW);
}

// Masks //
#define FLAG_MASK          0b1100000000
#define DIRECTION_MASK     0b0000001111

// Special //
#define HARDWARE_INTERRUPT 0b1000000000
#define REM                0b0100000000

// Direction //
#define STATE_STIL         0b0000000000
#define RECHTS             0b0000001000
#define RECHTS_VOOR        0b0000001001
#define RECHTS_ACHTER      0b0000001010
#define LINKS              0b0000000100
#define LINKS_VOOR         0b0000000101
#define LINKS_ACHTER       0b0000000110
#define ONDER              0b0000000010
#define BOVEN              0b0000000001

// Received data //
void handleReceivedData(uint16_t data) {
  uint8_t flagBits = (data & FLAG_MASK) >> 8;
  uint8_t directionBits = data & DIRECTION_MASK;

  switch (flagBits) {
    case 0b10:
      Serial.println("Hardware interrupt");
      stopMotors();
      return;
    case 0b01:
      Serial.println("Brake");
      stopMotors();
      return;
    case 0b00:
      break;
    default:
      Serial.println("Unknown flag");
      stopMotors();
      return;
  }

  switch (directionBits) {
    case STATE_STIL:
      Serial.println("IDLE");
      stopMotors();
      break;
    case RECHTS:
      Serial.println("Right");
      rightSharp();
      break;
    case RECHTS_VOOR:
      Serial.println("Right + Forward");
      right();
      break;
    case RECHTS_ACHTER:
      Serial.println("Right + Reverse");
      backwardRight();
      break;
    case LINKS:
      Serial.println("Left");
      leftSharp();
      break;
    case LINKS_VOOR:
      Serial.println("Left + Forward");
      left();
      break;
    case LINKS_ACHTER:
      Serial.println("Left + Reverse");
      backwardLeft();
      break;
    case ONDER:
      Serial.println("Reverse");
      backward();
      break;
    case BOVEN:
      Serial.println("Forward");
      forward();
      break;
    default:
      Serial.println("Unknown direction");
      stopMotors();
      break;
  }
}

// Setup //
void setup() {
  Serial.begin(115200);

  pinMode(output1, OUTPUT);
  pinMode(output2, OUTPUT);
  pinMode(output3, OUTPUT);
  pinMode(output4, OUTPUT);

  BLEDevice::init("");
  pClient = BLEDevice::createClient();
  Serial.println("BLE Client Initialized.");

  BLEAddress bleAddress(BLE_SERVER_MAC);
  if (pClient->connect(bleAddress)) {
    Serial.println("Successfully connected to the BLE server!");

    pRemoteService = pClient->getService(BLEUUID(SERVICE_UUID));
    if (pRemoteService) {
      pRemoteCharacteristic = pRemoteService->getCharacteristic(CHARACTERISTIC_UUID);
      if (pRemoteCharacteristic) {
        Serial.println("Found characteristic!");
        connected = true;
      } else {
        Serial.println("Characteristic not found.");
      }
    } else {
      Serial.println("Service not found.");
    }
  } else {
    Serial.println("Failed to connect to the BLE server.");
  }

  stopMotors();
}

// Main loop //
void loop() {
  if (connected) {
    if (!pClient->isConnected()) {
      Serial.println("Disconnected from BLE server.");
      connected = false;
    } else {
      if (pRemoteCharacteristic) {
        String value = pRemoteCharacteristic->readValue();
        if (value.length() == 10) {
          Serial.print("Received data: ");
          Serial.println(value);

          lastReceivedTime = millis();

          // Zet 10-bit binaire string om naar integer
          uint16_t data = 0;
          for (int i = 0; i < 10; i++) {
            data |= (value.charAt(i) == '1' ? 1 : 0) << (9 - i);
          }

          handleReceivedData(data);
        }
      }

      if (millis() - lastReceivedTime > timeout) {
        Serial.println("Disconnected due to inactivity.");
        connected = false;
      }
    }
  } else {
    Serial.println("Waiting for connection...");
    BLEAddress bleAddress(BLE_SERVER_MAC);
    if (pClient->connect(bleAddress)) {
      Serial.println("Reconnected to BLE server!");
      connected = true;
    }
    stopMotors();
  }

  delay(100);
}
